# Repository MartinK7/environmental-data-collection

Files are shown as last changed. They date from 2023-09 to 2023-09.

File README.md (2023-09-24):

# Environmental-data-collection

##  TASK
Cílem projektu je sestavit systém, který bude schopen monitorovat vybrané meteorologická, případně hydropedologická data a odesílat je na servery pro IoT jako např. Thing Network, ThingSpeak, ubidots, aj. Snahou bude získaná data nejen archivovat, ale poskytnout je některé z předpovědních sítí jako OpenWeather, Weather Underground apod. MP(K)C-M2E: Prostudujte dostupné koncepce pro měření vybraných meteorologických veličin. Prostudujte možnosti řídícího prvku měřícího systému např. AVR, Raspberry Pi, STM32, ESP, aj. a zvolte ideální variantu. Prostudujte vhodné komunikační rozhraní pro přenos dat. Vyberte veškeré komponenty, navrhněte blokové schéma zařízení, sestavte obvodové zapojení, DPS a realizujte je. Při návrhu dbejte na nízkou spotřebu finálního zařízení a odolnost ve venkovním prostředí. MP(K)C-MSE: Zařízení zkompletujte, oživte, naprogramujte obslužné firmwary a zprovozněte sběr dat. Proveďte detailní testování celého systému a porovnejte jej s jinými řešeními. Měřená data poskytněte některé ze sítě pro sběr a předpověď počasí. Pozn.: Systém bude v budoucnu nasazen pro měřící stanici na střeše URELu. Výhodou je zkušenost s vývojem elektroniky a s programováním v jazyce C/C++ nebo Python.

## Basic literary sources
[1] KOUSAL, Martin. IoT monitoring ovzduší. Brno: Vysoké učení technické v Brně, Fakulta elektrotechniky a komunikačních technologií, Ústav radioelektroniky, 2022, 68 s. Bakalářská práce. Vedoucí práce: doc. Ing. Tomáš Frýza, Ph.D.

[2] Weather stations. OpenWeather [online]. 2022 [cit. 2022-05-24]. Dostupné z: https://openweathermap.org/stations

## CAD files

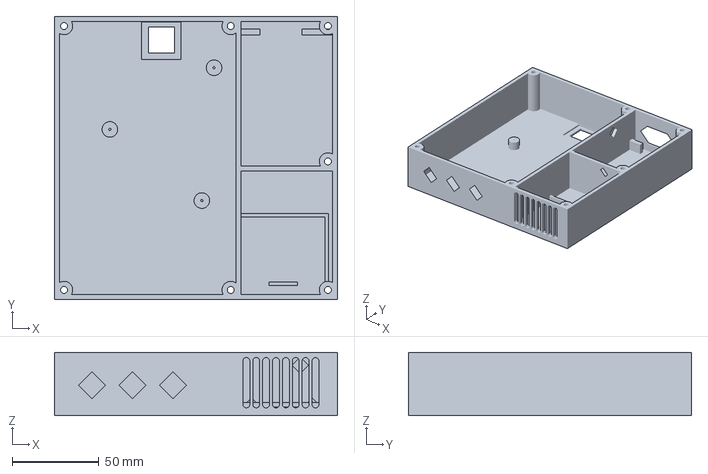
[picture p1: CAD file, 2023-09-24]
models/box4.3mf
163.0 x 163.0 x 36.5 mm

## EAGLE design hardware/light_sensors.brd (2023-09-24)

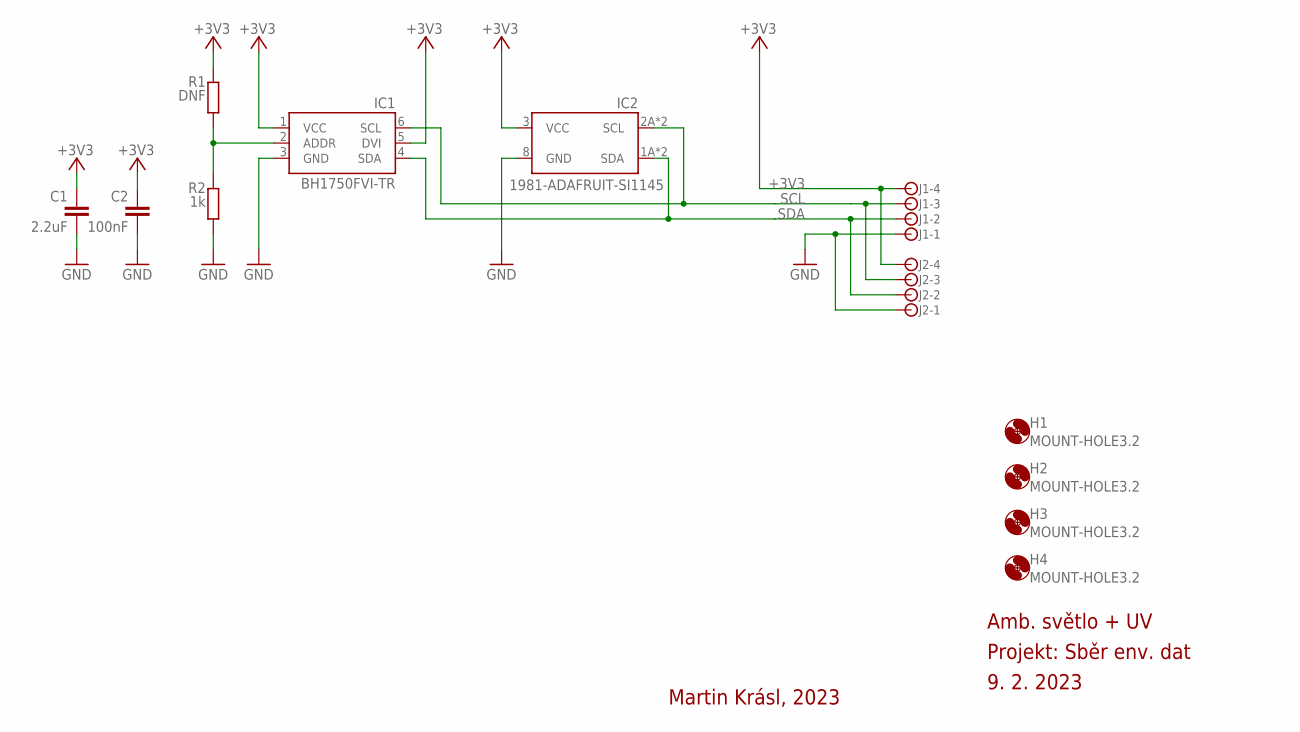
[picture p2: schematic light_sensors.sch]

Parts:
C1: 2.2uF; C0805
C2: 100nF; C0402
H1, H2, H3, H4: MOUNT-HOLE3.2; 3,2
IC1: BH1750FVI-TR; WSOF6
IC2: 1981-ADAFRUIT-SI1145
J1, J2: JST-XH-4; B4B-XH-A
R1: DNF; R0402
R2: 1k; R0402

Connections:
+3V3: C1.1, C2.1, IC1.1 (VCC), IC1.5 (DVI), IC2.3 (VCC), J1.4, J2.4, R1.2
GND: C1.2, C2.2, IC1.3 (GND), IC2.8 (GND), J1.1, J2.1, R2.1
unnamed: IC1.2 (ADDR), R1.1, R2.2
SCL: IC1.6 (SCL), IC2.2A (SCL), IC2.2B (SCL), J1.3, J2.3
SDA: IC1.4 (SDA), IC2.1A (SDA), IC2.1B (SDA), J1.2, J2.2

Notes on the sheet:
Amb. světlo + UV
Projekt: Sběr env. dat
9. 2. 2023
Martin Krásl, 2023

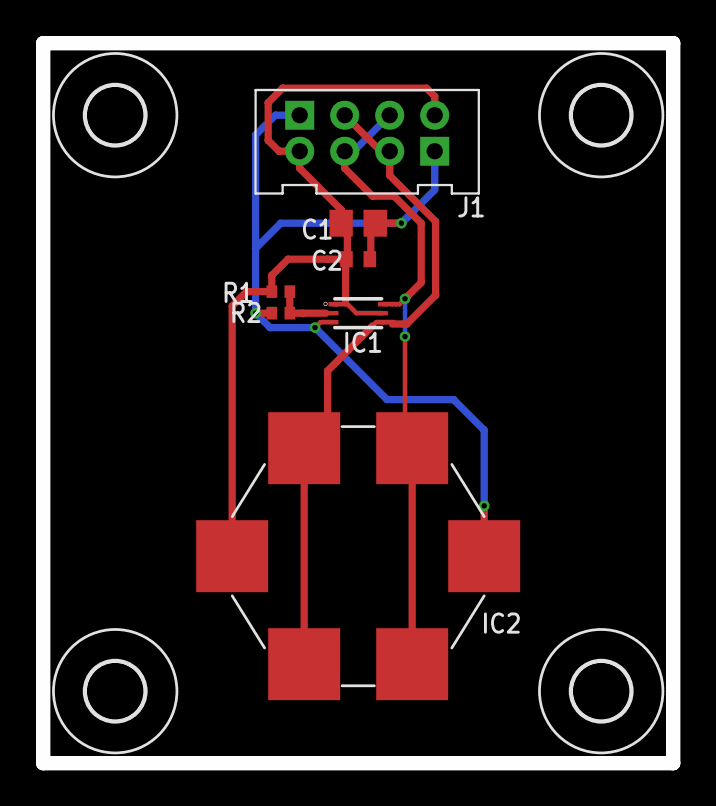
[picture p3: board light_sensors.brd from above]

Board: 2 copper layers, 35.0 x 40.0 mm, 12 parts (1 on the bottom side), 5 nets.

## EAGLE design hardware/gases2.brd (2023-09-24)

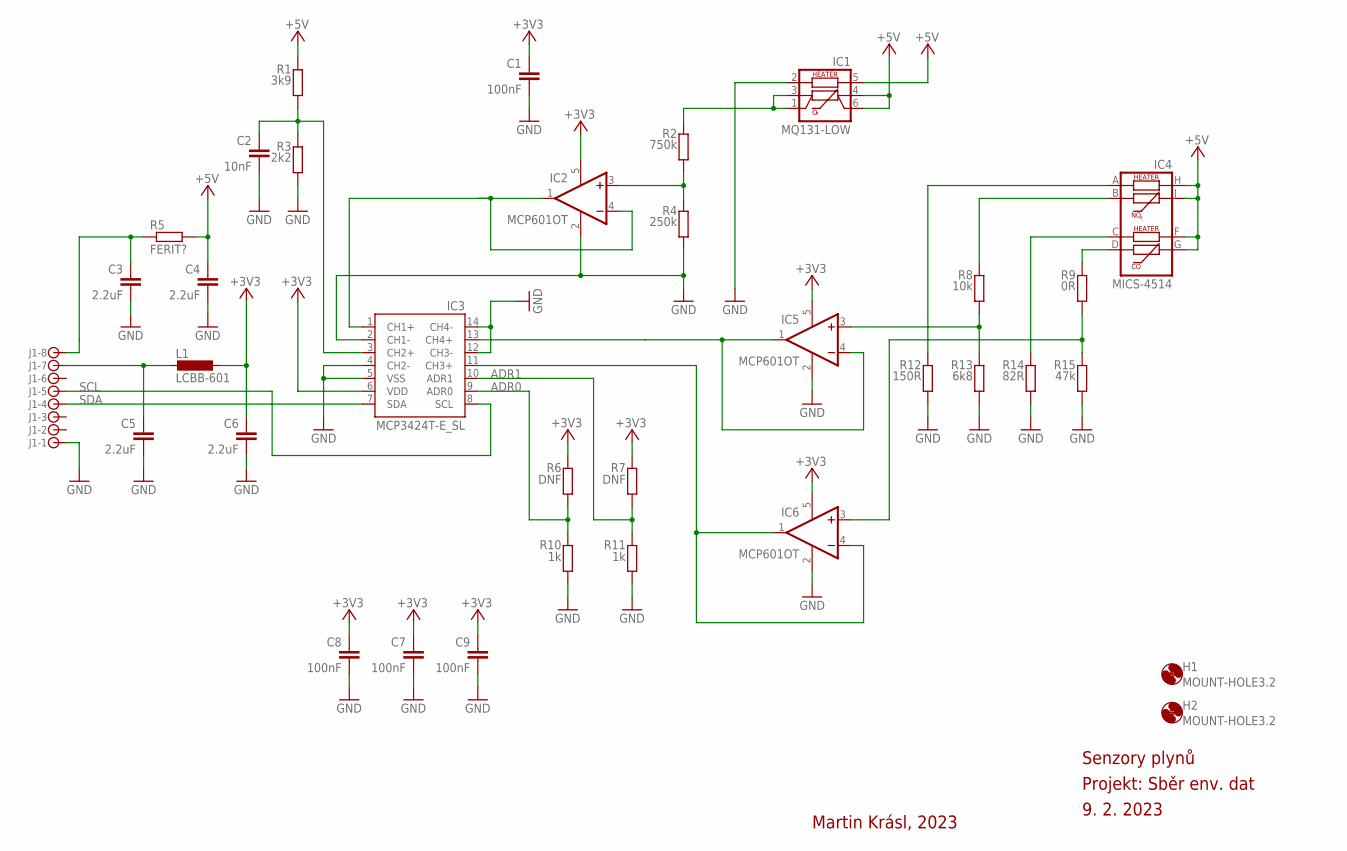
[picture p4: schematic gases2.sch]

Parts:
C1, C7, C8, C9: 100nF; C0402
C2: 10nF; C0402
C3, C4, C5, C6: 2.2uF; C0402
H1, H2: MOUNT-HOLE3.2; 3,2
IC1: MQ131-LOW
IC2, IC5, IC6: MCP601OT; SOT23-5
IC3: MCP3424T-E_SL; SOIC127P600X175-14N
IC4: MICS-4514
J1: JST-XH-8; B8B-XH-A
L1: LCBB-601; L2012C
R1: 3k9; R0402
R2: 750k; R0402
R3: 2k2; R0402
R4: 250k; R0402
R5: FERIT?; R0805
R6, R7: DNF; R0402
R8: 10k; R0402
R9: 0R; R0402
R10, R11: 1k; R0402
R12: 150R; R1206
R13: 6k8; R0402
R14: 82R; R1206
R15: 47k; R0402

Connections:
+3V3: C1.1, C6.1, C7.1, C8.1, C9.1, IC2.5 (V+), IC3.6 (VDD), IC5.5 (V+), IC6.5 (V+), L1.1, R6.2, R7.2
+5V: C4.1, IC1.4, IC1.5, IC1.6, IC4.F, IC4.G, IC4.H, IC4.J, R1.2, R5.2
ADR0: IC3.9 (ADR0), R6.1, R10.2
ADR1: IC3.10 (ADR1), R7.1, R11.2
GND: C1.2, C2.2, C3.2, C4.2, C5.2, C6.2, C7.2, C8.2, C9.2, IC1.2, IC2.2 (V-), IC3.2 (CH1-), IC3.4 (CH2-), IC3.5 (VSS), IC3.12 (CH3-), IC3.14 (CH4-), IC5.2 (V-), IC6.2 (V-), J1.1, R3.1, R4.1, R10.1, R11.1, R12.1, R13.1, R14.1, R15.1
unnamed: IC2.1 (OUT), IC2.4 (-IN), IC3.1 (CH1+)
unnamed: C2.1, IC3.3 (CH2+), R1.1, R3.2
unnamed: C3.1, J1.8, R5.1
unnamed: IC2.3 (+IN), R2.1, R4.2
unnamed: IC1.1, IC1.3, R2.2
unnamed: IC4.B, R8.2
unnamed: IC4.D, R9.2
unnamed: IC5.3 (+IN), R8.1, R13.2
unnamed: IC4.A, R12.2
unnamed: IC4.C, R14.2
unnamed: C5.1, J1.7, L1.2
unnamed: IC6.3 (+IN), R9.1, R15.2
unnamed: IC3.13 (CH4+), IC5.1 (OUT), IC5.4 (-IN)
unnamed: IC3.11 (CH3+), IC6.1 (OUT), IC6.4 (-IN)
SCL: IC3.8 (SCL), J1.5
SDA: IC3.7 (SDA), J1.4

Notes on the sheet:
Senzory plynů
Projekt: Sběr env. dat
9. 2. 2023
Martin Krásl, 2023

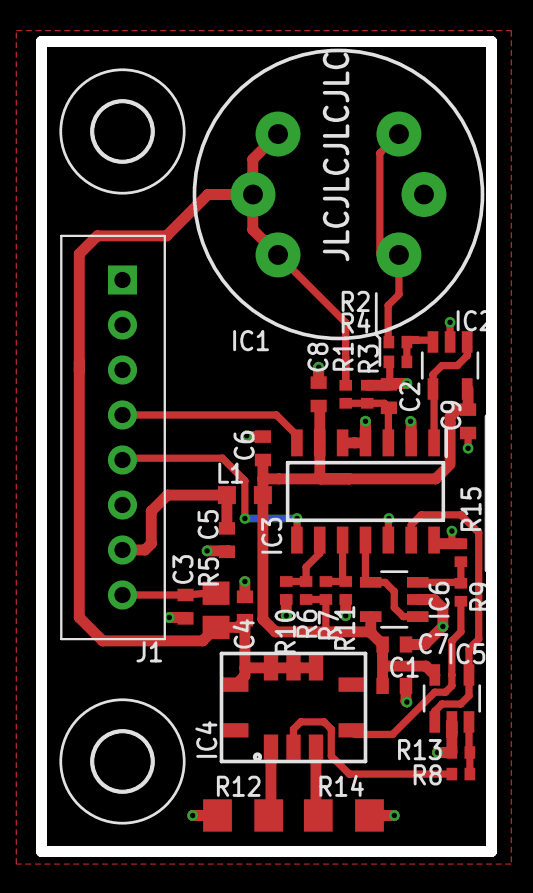
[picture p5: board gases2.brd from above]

Board: 2 copper layers, 25.0 x 45.0 mm, 34 parts (0 on the bottom side), 21 nets.

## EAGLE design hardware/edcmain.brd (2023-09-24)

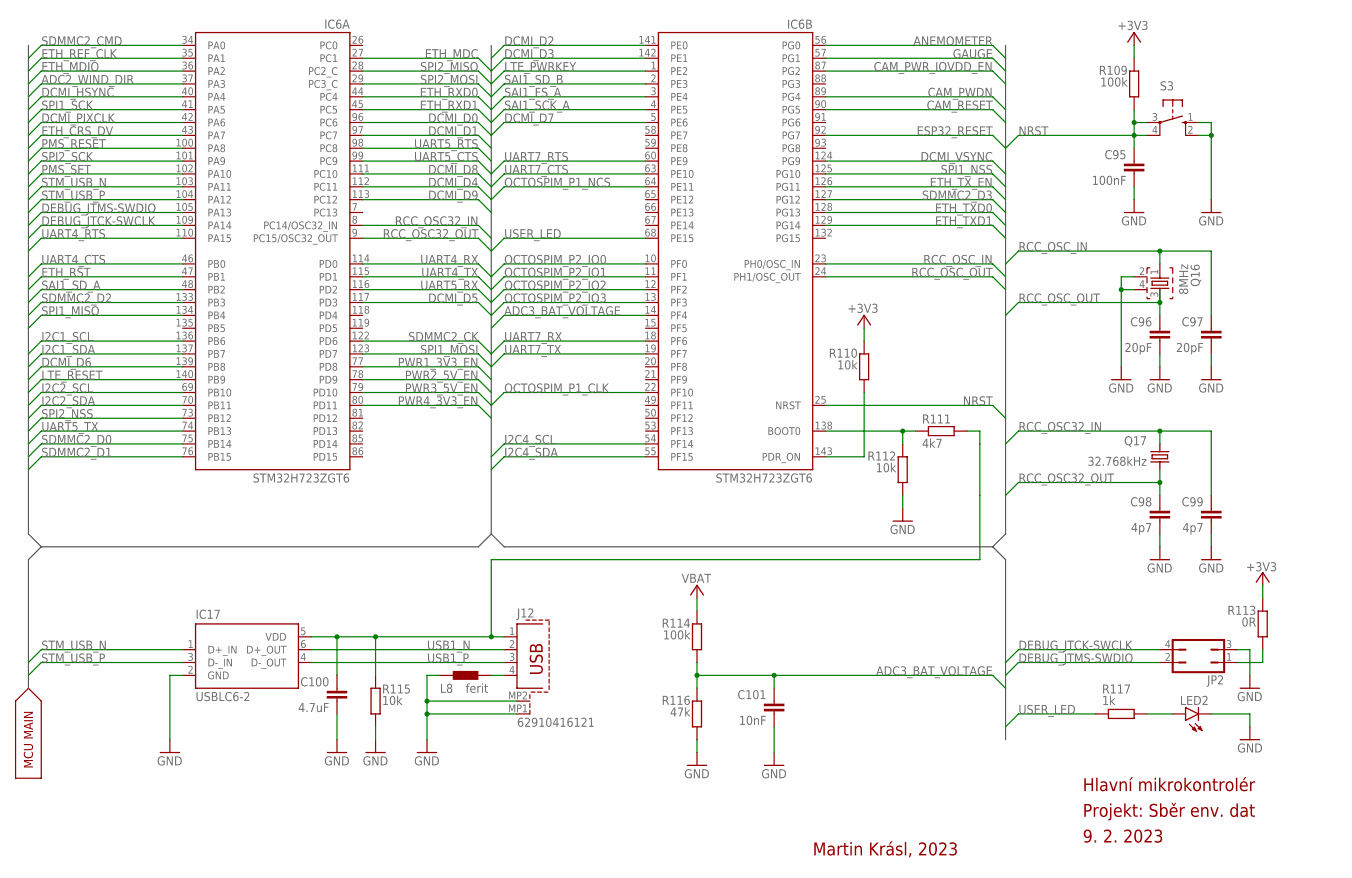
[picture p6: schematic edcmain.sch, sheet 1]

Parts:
C95: 100nF; C0402
C96, C97: 20pF; C0402
C98, C99: 4p7; C0402
C100: 4.7uF; C0402
C101: 10nF; C0402
IC6: STM32H723ZGT6; QFP50P2200X2200X160-144N
IC17: USBLC6-2; SOT23-6
J12: 62910416121
JP2: JP2Q
L8: ferit; 0402
LED2: LEDCHIP-LED0805; CHIP-LED0805
Q16: 8MHz; CRYSTAL3.2X2.5
Q17: 32.768kHz; NX3215SA32768KEXS00AMU00003
R109, R114: 100k; R0402
R110, R112, R115: 10k; R0402
R111: 4k7; R0402
R113: 0R; R0402
R116: 47k; R0402
R117: 1k; R0402
S3: 10-XX; B3F-10XX

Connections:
+3V3: R109.2, R110.2, R113.2; also elsewhere on the board
ADC2_WIND_DIR: IC6.37 (PA3); also elsewhere on the board
ADC3_BAT_VOLTAGE: C101.1, IC6.14 (PF4), R114.1, R116.2
ANEMOMETER: IC6.56 (PG0); also elsewhere on the board
CAM_PWDN: IC6.89 (PG4); also elsewhere on the board
CAM_PWR_IOVDD_EN: IC6.87 (PG2); also elsewhere on the board
CAM_RESET: IC6.90 (PG5); also elsewhere on the board
DCMI_D0: IC6.96 (PC6); also elsewhere on the board
DCMI_D1: IC6.97 (PC7); also elsewhere on the board
DCMI_D2: IC6.141 (PE0); also elsewhere on the board
DCMI_D3: IC6.142 (PE1); also elsewhere on the board
DCMI_D4: IC6.112 (PC11); also elsewhere on the board
DCMI_D5: IC6.117 (PD3); also elsewhere on the board
DCMI_D6: IC6.139 (PB8); also elsewhere on the board
DCMI_D7: IC6.5 (PE6); also elsewhere on the board
DCMI_D8: IC6.111 (PC10); also elsewhere on the board
DCMI_D9: IC6.113 (PC12); also elsewhere on the board
DCMI_HSYNC: IC6.40 (PA4); also elsewhere on the board
DCMI_PIXCLK: IC6.42 (PA6); also elsewhere on the board
DCMI_VSYNC: IC6.124 (PG9); also elsewhere on the board
DEBUG_JTCK-SWCLK: IC6.109 (PA14), JP2.4
DEBUG_JTMS-SWDIO: IC6.105 (PA13), JP2.2
ESP32_RESET: IC6.92 (PG7); also elsewhere on the board
ETH_CRS_DV: IC6.43 (PA7); also elsewhere on the board
ETH_MDC: IC6.27 (PC1); also elsewhere on the board
ETH_MDIO: IC6.36 (PA2); also elsewhere on the board
ETH_REF_CLK: IC6.35 (PA1); also elsewhere on the board
ETH_RST: IC6.47 (PB1); also elsewhere on the board
ETH_RXD0: IC6.44 (PC4); also elsewhere on the board
ETH_RXD1: IC6.45 (PC5); also elsewhere on the board
ETH_TXD0: IC6.128 (PG13); also elsewhere on the board
ETH_TXD1: IC6.129 (PG14); also elsewhere on the board
ETH_TX_EN: IC6.126 (PG11); also elsewhere on the board
GAUGE: IC6.57 (PG1); also elsewhere on the board
GND: C95.2, C96.2, C97.2, C98.2, C99.2, C100.2, C101.2, IC17.2 (GND), J12.MP1, J12.MP2, JP2.3, L8.1, LED2.C, Q16.2, Q16.4, R112.1, R115.1, R116.1, S3.1 (S), S3.2 (S1); also elsewhere on the board
I2C1_SCL: IC6.136 (PB6); also elsewhere on the board
I2C1_SDA: IC6.137 (PB7); also elsewhere on the board
I2C2_SCL: IC6.69 (PB10); also elsewhere on the board
I2C2_SDA: IC6.70 (PB11); also elsewhere on the board
I2C4_SCL: IC6.54 (PF14); also elsewhere on the board
I2C4_SDA: IC6.55 (PF15); also elsewhere on the board
LTE_PWRKEY: IC6.1 (PE2); also elsewhere on the board
LTE_RESET: IC6.140 (PB9); also elsewhere on the board
unnamed: C100.1, IC17.5 (VDD), J12.1, R111.2, R115.2
unnamed: LED2.A, R117.2
unnamed: IC6.143 (PDR_ON), R110.1
unnamed: IC6.138 (BOOT0), R111.1, R112.2
unnamed: J12.4, L8.2
unnamed: JP2.1, R113.1
NRST: C95.1, IC6.25 (NRST), R109.1, S3.3, S3.4 (P1)
OCTOSPIM_P1_CLK: IC6.22 (PF10); also elsewhere on the board
OCTOSPIM_P1_NCS: IC6.64 (PE11); also elsewhere on the board
OCTOSPIM_P2_IO0: IC6.10 (PF0); also elsewhere on the board
OCTOSPIM_P2_IO1: IC6.11 (PF1); also elsewhere on the board
OCTOSPIM_P2_IO2: IC6.12 (PF2); also elsewhere on the board
OCTOSPIM_P2_IO3: IC6.13 (PF3); also elsewhere on the board
PMS_RESET: IC6.100 (PA8); also elsewhere on the board
PMS_SET: IC6.102 (PA10); also elsewhere on the board
PWR1_3V3_EN: IC6.77 (PD8); also elsewhere on the board
PWR2_5V_EN: IC6.78 (PD9); also elsewhere on the board
PWR3_5V_EN: IC6.79 (PD10); also elsewhere on the board
PWR4_3V3_EN: IC6.80 (PD11); also elsewhere on the board
RCC_OSC32_IN: C99.1, IC6.8 (PC14/OSC32_IN), Q17.2
RCC_OSC32_OUT: C98.1, IC6.9 (PC15/OSC32_OUT), Q17.1
RCC_OSC_IN: C97.1, IC6.23 (PH0/OSC_IN), Q16.1
RCC_OSC_OUT: C96.1, IC6.24 (PH1/OSC_OUT), Q16.3
SAI1_FS_A: IC6.3 (PE4); also elsewhere on the board
SAI1_SCK_A: IC6.4 (PE5); also elsewhere on the board
SAI1_SD_A: IC6.48 (PB2); also elsewhere on the board
SAI1_SD_B: IC6.2 (PE3); also elsewhere on the board
SDMMC2_CK: IC6.122 (PD6); also elsewhere on the board
SDMMC2_CMD: IC6.34 (PA0); also elsewhere on the board
SDMMC2_D0: IC6.75 (PB14); also elsewhere on the board
SDMMC2_D1: IC6.76 (PB15); also elsewhere on the board
SDMMC2_D2: IC6.133 (PB3); also elsewhere on the board
SDMMC2_D3: IC6.127 (PG12); also elsewhere on the board
SPI1_MISO: IC6.134 (PB4); also elsewhere on the board
SPI1_MOSI: IC6.123 (PD7); also elsewhere on the board
SPI1_NSS: IC6.125 (PG10); also elsewhere on the board
SPI1_SCK: IC6.41 (PA5); also elsewhere on the board
SPI2_MISO: IC6.28 (PC2_C); also elsewhere on the board
SPI2_MOSI: IC6.29 (PC3_C); also elsewhere on the board
SPI2_NSS: IC6.73 (PB12); also elsewhere on the board
SPI2_SCK: IC6.101 (PA9); also elsewhere on the board
STM_USB_N: IC6.103 (PA11), IC17.1 (D+_IN)
STM_USB_P: IC6.104 (PA12), IC17.3 (D-_IN)
UART4_CTS: IC6.46 (PB0); also elsewhere on the board
UART4_RTS: IC6.110 (PA15); also elsewhere on the board
UART4_RX: IC6.114 (PD0); also elsewhere on the board
UART4_TX: IC6.115 (PD1); also elsewhere on the board
UART5_CTS: IC6.99 (PC9); also elsewhere on the board
UART5_RTS: IC6.98 (PC8); also elsewhere on the board
UART5_RX: IC6.116 (PD2); also elsewhere on the board
UART5_TX: IC6.74 (PB13); also elsewhere on the board
UART7_CTS: IC6.63 (PE10); also elsewhere on the board
UART7_RTS: IC6.60 (PE9); also elsewhere on the board
UART7_RX: IC6.18 (PF6); also elsewhere on the board
UART7_TX: IC6.19 (PF7); also elsewhere on the board
USB1_N: IC17.6 (D+_OUT), J12.2
USB1_P: IC17.4 (D-_OUT), J12.3
USER_LED: IC6.68 (PE15), R117.1
VBAT: R114.2; also elsewhere on the board

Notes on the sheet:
MCU MAIN
Hlavní mikrokontrolér
Projekt: Sběr env. dat
9. 2. 2023
Martin Krásl, 2023

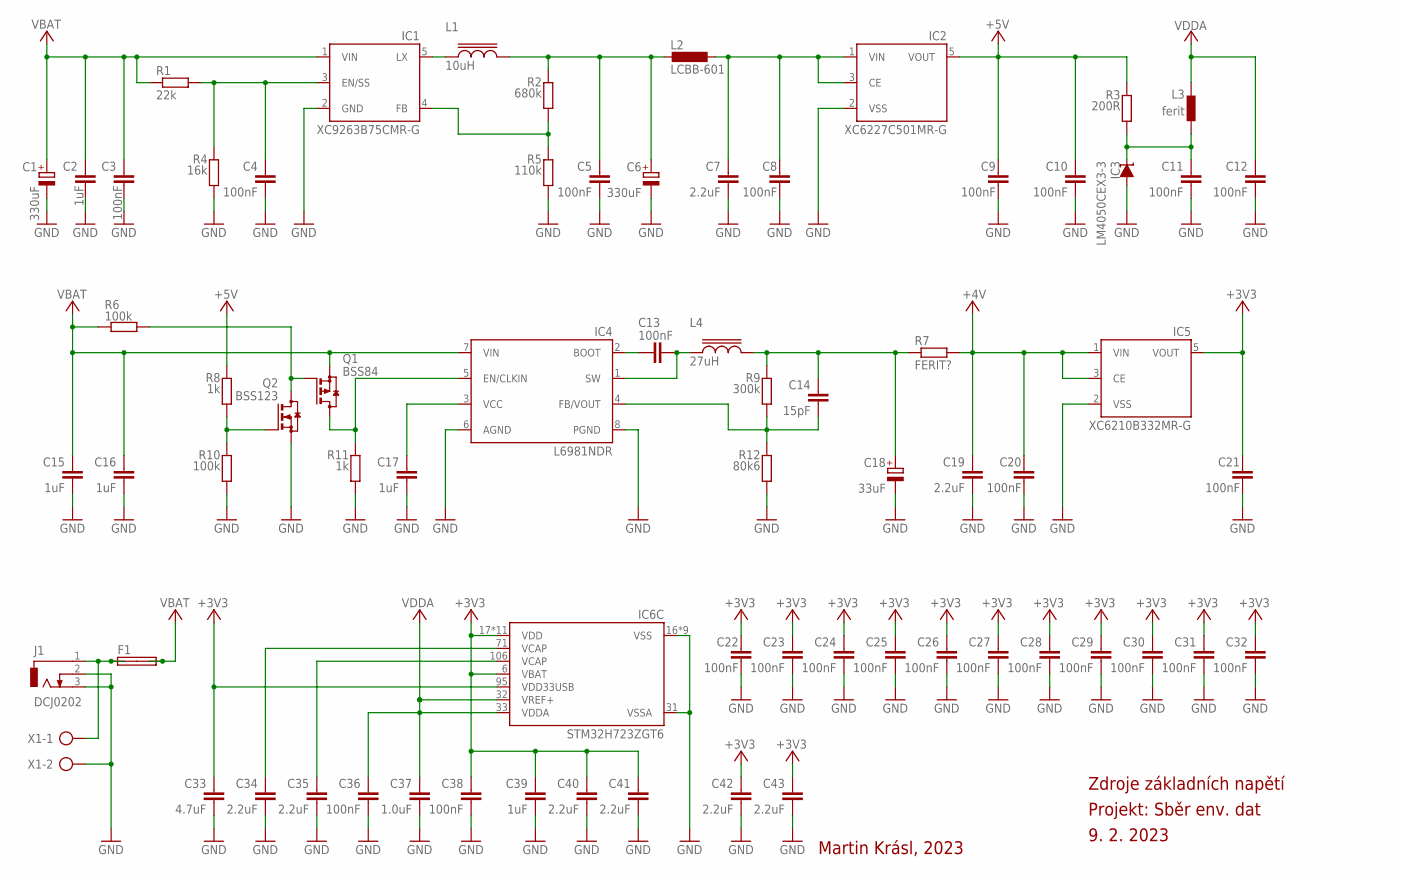
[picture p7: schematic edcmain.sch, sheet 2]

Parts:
C1, C6: 330uF; PANASONIC_G
C2, C15, C16: 1uF; C0805
C3, C4, C5, C8, C9, C10, C11, C12, C13, C20, C21, C22, C23, C24, C25, C26, C27, C28, C29, C30, C31, C32, C36, C38: 100nF; C0402
C7, C34, C35, C43: 2.2uF; C0805
C14: 15pF; C0402
C17, C39: 1uF; C0402
C18: 33uF; PANASONIC_G
C19, C40, C41, C42: 2.2uF; C0402
C33: 4.7uF; C0402
C37: 1.0uF; C0402
F1: SHK20L
IC1: XC9263B75CMR-G; SOT95P280X130-5N
IC2: XC6227C501MR-G; SOT95P280X130-5N
IC3: LM4050CEX3-3; SC70-3
IC4: L6981NDR; SOIC127P600X175-8N
IC5: XC6210B332MR-G; SOT95P280X130-5N
IC6: STM32H723ZGT6; QFP50P2200X2200X160-144N
IMG1: IMAGEPRINT; RD_14_24_PRINT
J1: DCJ0202
L1: 10uH; L6
L2: LCBB-601; L2012C
L3: ferit; 0402
L4: 27uH; L6
Q1: BSS84; SOT23
Q2: BSS123; SOT23
R1: 22k; R0402
R2: 680k; R0402
R3: 200R; R0402
R4: 16k; R0402
R5: 110k; R0402
R6, R10: 100k; R0402
R7: FERIT?; R2010
R8, R11: 1k; R0402
R9: 300k; R0402
R12: 80k6; R0402
X1: AK500/2

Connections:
+3V3: C21.1, C22.1, C23.1, C24.1, C25.1, C26.1, C27.1, C28.1, C29.1, C30.1, C31.1, C32.1, C33.1, C38.1, C39.1, C40.1, C41.1, C42.1, C43.1, IC5.5 (VOUT), IC6.6 (VBAT), IC6.17 (VDD), IC6.30 (VDD), IC6.39 (VDD), IC6.52 (VDD), IC6.62 (VDD), IC6.72 (VDD), IC6.84 (VDD), IC6.95 (VDD33USB), IC6.108 (VDD), IC6.121 (VDD), IC6.131 (VDD), IC6.144 (VDD); also elsewhere on the board
+4V: C19.1, C20.1, IC5.1 (VIN), IC5.3 (CE), R7.2; also elsewhere on the board
+5V: C9.1, C10.1, IC2.5 (VOUT), R3.2, R8.2; also elsewhere on the board
GND: C1.-, C2.2, C3.2, C4.2, C5.2, C6.-, C7.2, C8.2, C9.2, C10.2, C11.2, C12.2, C15.2, C16.2, C17.2, C18.-, C19.2, C20.2, C21.2, C22.2, C23.2, C24.2, C25.2, C26.2, C27.2, C28.2, C29.2, C30.2, C31.2, C32.2, C33.2, C34.2, C35.2, C36.2, C37.2, C38.2, C39.2, C40.2, C41.2, C42.2, C43.2, IC1.2 (GND), IC2.2 (VSS), IC3.1 (A), IC4.6 (AGND), IC4.8 (PGND), IC5.2 (VSS), IC6.16 (VSS), IC6.31 (VSSA), IC6.38 (VSS), IC6.51 (VSS), IC6.61 (VSS), IC6.83 (VSS), IC6.94 (VSS), IC6.107 (VSS), IC6.120 (VSS), IC6.130 (VSS), J1.2, J1.3, Q2.2 (S), R4.1, R5.1, R10.1, R11.1, R12.1, X1.2; also elsewhere on the board
unnamed: F1.1A, F1.1B, J1.1, X1.1
unnamed: C34.1, IC6.71 (VCAP)
unnamed: C35.1, IC6.106 (VCAP)
unnamed: C11.1, IC3.2 (C), L3.1, R3.1
unnamed: C17.1, IC4.3 (VCC)
unnamed: C7.1, C8.1, IC2.1 (VIN), IC2.3 (CE), L2.1
unnamed: C5.1, C6.+, L1.P$2, L2.2, R2.2
unnamed: IC1.5 (LX), L1.P$1
unnamed: IC1.4 (FB), R2.1, R5.2
unnamed: C4.1, IC1.3 (EN/SS), R1.2, R4.2
unnamed: C14.2, IC4.4 (FB/VOUT), R9.1, R12.2
unnamed: C13.1, IC4.2 (BOOT)
unnamed: C13.2, IC4.1 (SW), L4.P$1
unnamed: C14.1, C18.+, L4.P$2, R7.1, R9.2
unnamed: Q1.1 (G), Q2.3 (D), R6.2
unnamed: IC4.5 (EN/CLKIN), Q1.3 (D), R11.2
unnamed: Q2.1 (G), R8.1, R10.2
VBAT: C1.+, C2.1, C3.1, C15.1, C16.1, F1.2A, F1.2B, IC1.1 (VIN), IC4.7 (VIN), Q1.2 (S), R1.1, R6.1; also elsewhere on the board
VDDA: C12.1, C36.1, C37.1, IC6.32 (VREF+), IC6.33 (VDDA), L3.2

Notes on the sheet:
Zdroje základních napětí
Projekt: Sběr env. dat
9. 2. 2023
Martin Krásl, 2023

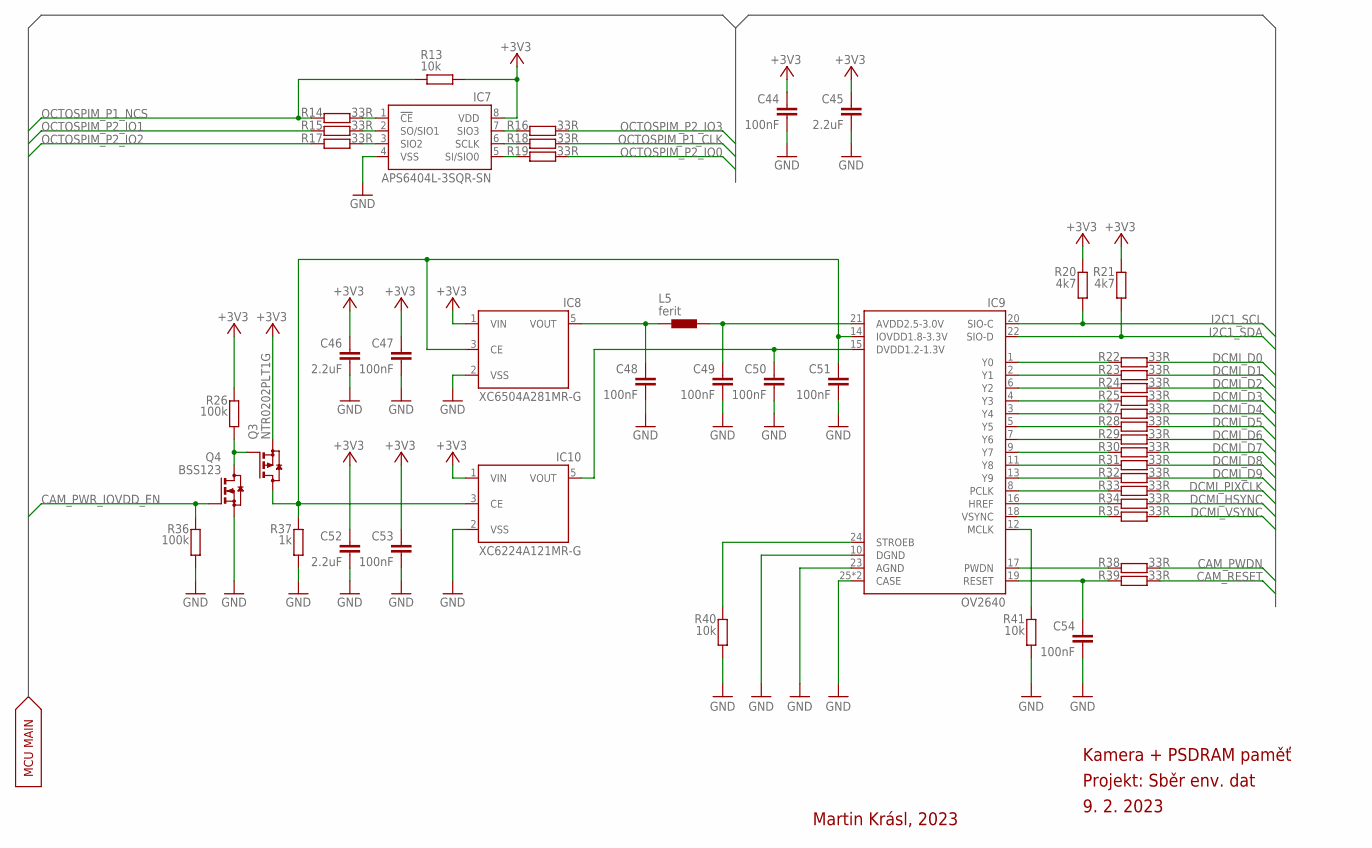
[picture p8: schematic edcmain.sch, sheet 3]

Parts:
C44, C47, C48, C49, C50, C51, C53, C54: 100nF; C0402
C45, C46: 2.2uF; C0402
C52: 2.2uF; C0805
IC7: APS6404L-3SQR-SN; SOP08
IC8: XC6504A281MR-G; SOT95P280X130-5N
IC9: OV2640; XF2M-2415-1A-SWAP
IC10: XC6224A121MR-G; SOT95P280X130-5N
L5: ferit; 0402
Q3: NTR0202PLT1G; SOT23
Q4: BSS123; SOT23
R13, R40, R41: 10k; R0402
R14, R15, R16, R17, R18, R19, R22, R23, R24, R25, R27, R28, R29, R30, R31, R32, R33, R34, R35, R38, R39: 33R; R0402
R20, R21: 4k7; R0402
R26, R36: 100k; R0402
R37: 1k; R0402

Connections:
+3V3: C44.1, C45.1, C46.1, C47.1, C52.1, C53.1, IC7.8 (VDD), IC8.1 (VIN), IC10.1 (VIN), Q3.2 (S), R13.2, R20.2, R21.2, R26.2; also elsewhere on the board
CAM_PWDN: R38.2; also elsewhere on the board
CAM_PWR_IOVDD_EN: Q4.1 (G), R36.2; also elsewhere on the board
CAM_RESET: R39.2; also elsewhere on the board
DCMI_D0: R22.2; also elsewhere on the board
DCMI_D1: R23.2; also elsewhere on the board
DCMI_D2: R24.2; also elsewhere on the board
DCMI_D3: R25.2; also elsewhere on the board
DCMI_D4: R27.2; also elsewhere on the board
DCMI_D5: R28.2; also elsewhere on the board
DCMI_D6: R29.2; also elsewhere on the board
DCMI_D7: R30.2; also elsewhere on the board
DCMI_D8: R31.2; also elsewhere on the board
DCMI_D9: R32.2; also elsewhere on the board
DCMI_HSYNC: R34.2; also elsewhere on the board
DCMI_PIXCLK: R33.2; also elsewhere on the board
DCMI_VSYNC: R35.2; also elsewhere on the board
GND: C44.2, C45.2, C46.2, C47.2, C48.2, C49.2, C50.2, C51.2, C52.2, C53.2, C54.2, IC7.4 (VSS), IC8.2 (VSS), IC9.10 (DGND), IC9.23 (AGND), IC9.25 (CASE), IC9.26 (CASE), IC10.2 (VSS), Q4.2 (S), R36.1, R37.1, R40.1, R41.1; also elsewhere on the board
I2C1_SCL: IC9.20 (SIO-C), R20.1; also elsewhere on the board
I2C1_SDA: IC9.22 (SIO-D), R21.1; also elsewhere on the board
unnamed: IC9.1 (Y0), R22.1
unnamed: IC9.2 (Y1), R23.1
unnamed: IC9.6 (Y2), R24.1
unnamed: IC9.4 (Y3), R25.1
unnamed: IC9.3 (Y4), R27.1
unnamed: IC9.5 (Y5), R28.1
unnamed: IC9.7 (Y6), R29.1
unnamed: IC9.9 (Y7), R30.1
unnamed: IC9.11 (Y8), R31.1
unnamed: IC9.13 (Y9), R32.1
unnamed: IC7.1 (!CE!), R14.2
unnamed: IC7.2 (SO/SIO1), R15.2
unnamed: IC7.3 (SIO2), R17.2
unnamed: IC7.7 (SIO3), R16.1
unnamed: IC7.6 (SCLK), R18.1
unnamed: IC7.5 (SI/SIO0), R19.1
unnamed: IC9.18 (VSYNC), R35.1
unnamed: IC9.16 (HREF), R34.1
unnamed: IC9.8 (PCLK), R33.1
unnamed: C48.1, IC8.5 (VOUT), L5.1
unnamed: C49.1, IC9.21 (AVDD2.5-3.0V), L5.2
unnamed: C50.1, IC9.15 (DVDD1.2-1.3V), IC10.5 (VOUT)
unnamed: IC9.24 (STROEB), R40.2
unnamed: IC9.17 (PWDN), R38.1
unnamed: IC9.12 (MCLK), R41.2
unnamed: C54.1, IC9.19 (RESET), R39.1
unnamed: Q3.1 (G), Q4.3 (D), R26.1
unnamed: C51.1, IC8.3 (CE), IC9.14 (IOVDD1.8-3.3V), IC10.3 (CE), Q3.3 (D), R37.2
OCTOSPIM_P1_CLK: R18.2; also elsewhere on the board
OCTOSPIM_P1_NCS: R13.1, R14.1; also elsewhere on the board
OCTOSPIM_P2_IO0: R19.2; also elsewhere on the board
OCTOSPIM_P2_IO1: R15.1; also elsewhere on the board
OCTOSPIM_P2_IO2: R17.1; also elsewhere on the board
OCTOSPIM_P2_IO3: R16.2; also elsewhere on the board

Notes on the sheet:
MCU MAIN
Kamera + PSDRAM paměť
Projekt: Sběr env. dat
9. 2. 2023
Martin Krásl, 2023

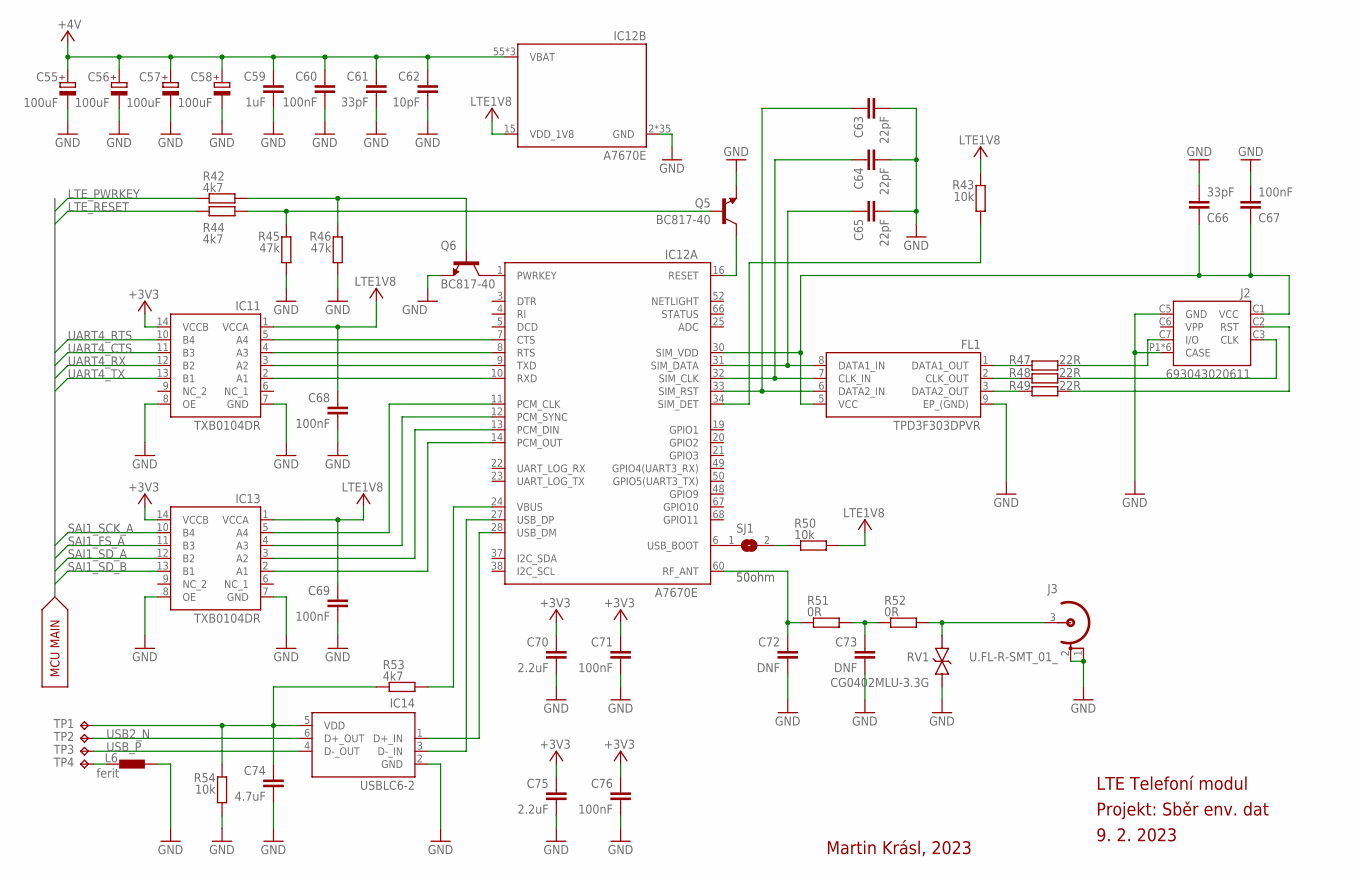
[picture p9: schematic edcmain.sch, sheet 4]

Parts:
C55, C56, C57, C58: 100uF; B/3528-21R
C59: 1uF; C0805
C60, C67, C68, C69, C71, C76: 100nF; C0402
C61, C66: 33pF; C0402
C62: 10pF; C0402
C63, C64, C65: 22pF; C0402
C70, C75: 2.2uF; C0402
C72, C73: DNF; C0402
C74: 4.7uF; C0402
FL1: TPD3F303DPVR; SON50P160X210X65-9N
IC11, IC13: TXB0104DR; SOIC127P600X175-14N
IC12: A7670E; A7670CLNSC
IC14: USBLC6-2; SOT23-6
J2: 693043020611
J3: U.FL-R-SMT_01_; UFLRSMT01
L6: ferit; 0402
Q5, Q6: BC817-40; SOT23-BEC
R42, R44, R53: 4k7; R0402
R43, R50, R54: 10k; R0402
R45, R46: 47k; R0402
R47, R48, R49: 22R; R0402
R51, R52: 0R; R0402
RV1: CG0402MLU-3.3G; VARC1005X41N
SJ1: SJ
TP1, TP2, TP3, TP4: TPB1,27; B1,27

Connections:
50OHM_1: C72.1, IC12.60 (RF_ANT), R51.1
50OHM_2: C73.1, R51.2, R52.1
50OHM_3: J3.3 (SIG), R52.2, RV1.1
+3V3: C70.1, C71.1, C75.1, C76.1, IC11.14 (VCCB), IC13.14 (VCCB); also elsewhere on the board
+4V: C55.+, C56.+, C57.+, C58.+, C59.1, C60.1, C61.1, C62.1, IC12.55 (VBAT), IC12.56 (VBAT), IC12.57 (VBAT); also elsewhere on the board
GND: C55.-, C56.-, C57.-, C58.-, C59.2, C60.2, C61.2, C62.2, C63.2, C64.2, C65.2, C66.2, C67.2, C68.2, C69.2, C70.2, C71.2, C72.2, C73.2, C74.2, C75.2, C76.2, FL1.9 (EP_(GND)), IC11.7 (GND), IC11.8 (OE), IC12.2 (GND), IC12.17 (GND), IC12.18 (GND), IC12.29 (GND), IC12.39 (GND), IC12.45 (GND), IC12.46 (GND), IC12.54 (GND), IC12.58 (GND), IC12.59 (GND), IC12.61 (GND), IC12.62 (GND), IC12.63 (GND), IC12.64 (GND), IC12.65 (GND), IC12.69 (GND), IC12.70 (GND), IC12.71 (GND), IC12.72 (GND), IC12.73 (GND), IC12.74 (GND), IC12.75 (GND), IC12.76 (GND), IC12.77 (GND), IC12.78 (GND), IC12.79 (GND), IC12.80 (GND), IC12.81 (GND), IC12.82 (GND), IC12.83 (GND), IC12.84 (GND), IC12.85 (GND), IC12.86 (GND), IC12.87 (GND), IC12.88 (GND), IC13.7 (GND), IC13.8 (OE), IC14.2 (GND), J2.C5 (GND), J2.P1 (CASE), J2.P2 (CASE), J2.P3 (CASE), J2.P4 (CASE), J2.P5 (CASE), J2.P6 (CASE), J3.1 (GND), J3.2 (GND), L6.1, Q5.E, Q6.E, R45.1, R46.1, R54.1, RV1.2; also elsewhere on the board
LTE1V8: C68.1, C69.1, IC11.1 (VCCA), IC12.15 (VDD_1V8), IC13.1 (VCCA), R43.2, R50.2
LTE_PWRKEY: R42.1; also elsewhere on the board
LTE_RESET: R44.1; also elsewhere on the board
unnamed: IC11.5 (A4), IC12.7 (CTS)
unnamed: IC11.4 (A3), IC12.8 (RTS)
unnamed: IC11.3 (A2), IC12.9 (TXD)
unnamed: IC11.2 (A1), IC12.10 (RXD)
unnamed: IC12.11 (PCM_CLK), IC13.5 (A4)
unnamed: IC12.12 (PCM_SYNC), IC13.4 (A3)
unnamed: IC12.13 (PCM_DIN), IC13.3 (A2)
unnamed: IC12.14 (PCM_OUT), IC13.2 (A1)
unnamed: C66.1, C67.1, FL1.5 (VCC), IC12.30 (SIM_VDD), J2.C1 (VCC)
unnamed: J2.C2 (RST), R49.2
unnamed: J2.C3 (CLK), R48.2
unnamed: J2.C7 (I/O), R47.2
unnamed: C63.1, FL1.6 (DATA2_IN), IC12.33 (SIM_RST)
unnamed: C64.1, FL1.7 (CLK_IN), IC12.32 (SIM_CLK)
unnamed: C65.1, FL1.8 (DATA1_IN), IC12.31 (SIM_DATA)
unnamed: IC12.34 (SIM_DET), R43.1
unnamed: C74.1, IC14.5 (VDD), R53.1, R54.2, TP1.TP
unnamed: L6.2, TP4.TP
unnamed: IC12.27 (USB_DP), IC14.3 (D-_IN)
unnamed: IC12.28 (USB_DM), IC14.1 (D+_IN)
unnamed: IC12.24 (VBUS), R53.2
unnamed: IC12.1 (PWRKEY), Q6.C
unnamed: IC12.6 (USB_BOOT), SJ1.1
unnamed: Q6.B, R42.2, R46.2
unnamed: IC12.16 (RESET), Q5.C
unnamed: R50.1, SJ1.2
unnamed: Q5.B, R44.2, R45.2
unnamed: FL1.3 (DATA2_OUT), R49.1
unnamed: FL1.2 (CLK_OUT), R48.1
unnamed: FL1.1 (DATA1_OUT), R47.1
SAI1_FS_A: IC13.11 (B3); also elsewhere on the board
SAI1_SCK_A: IC13.10 (B4); also elsewhere on the board
SAI1_SD_A: IC13.12 (B2); also elsewhere on the board
SAI1_SD_B: IC13.13 (B1); also elsewhere on the board
UART4_CTS: IC11.11 (B3); also elsewhere on the board
UART4_RTS: IC11.10 (B4); also elsewhere on the board
UART4_RX: IC11.12 (B2); also elsewhere on the board
UART4_TX: IC11.13 (B1); also elsewhere on the board
USB2_N: IC14.6 (D+_OUT), TP2.TP
USB_P: IC14.4 (D-_OUT), TP3.TP

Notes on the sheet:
MCU MAIN
50ohm
LTE Telefoní modul
Projekt: Sběr env. dat
9. 2. 2023
Martin Krásl, 2023

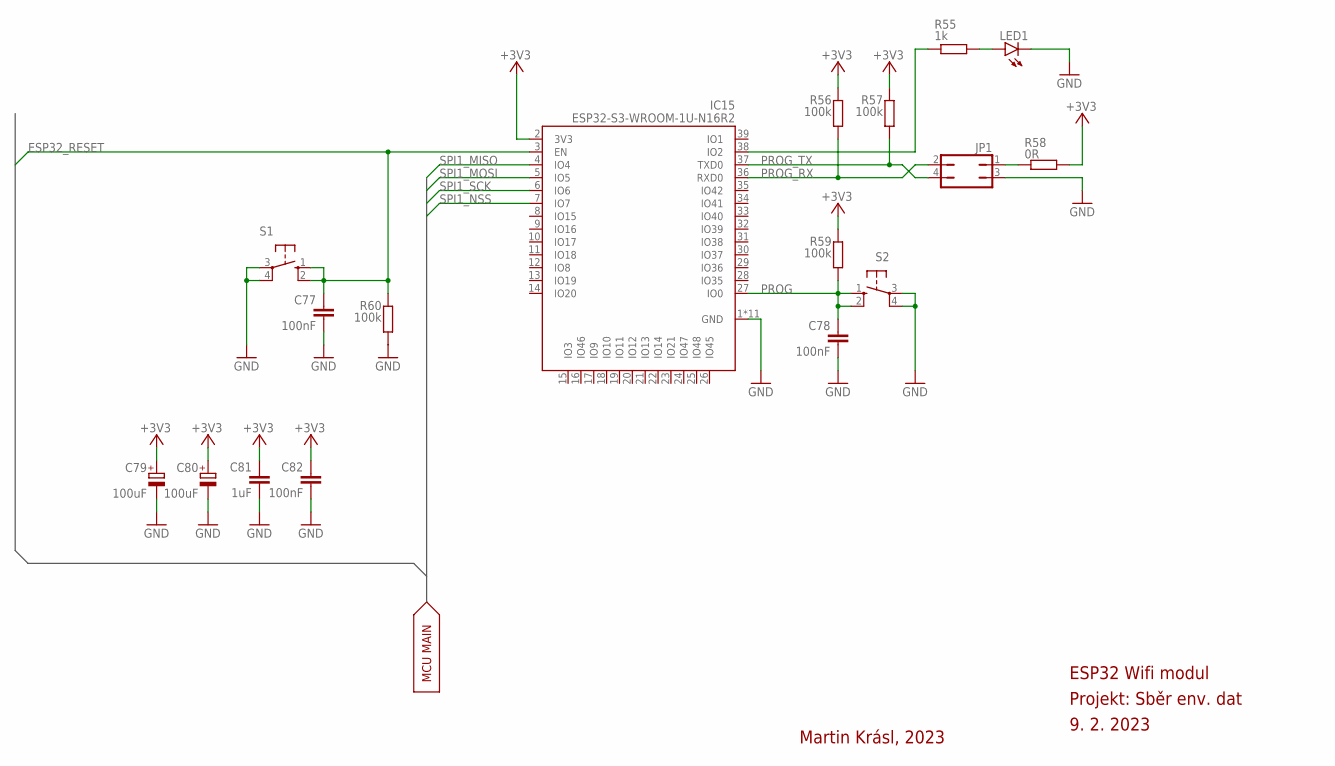
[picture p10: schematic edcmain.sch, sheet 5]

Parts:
C77, C78, C82: 100nF; C0402
C79, C80: 100uF; B/3528-21R
C81: 1uF; C0805
IC15: ESP32-S3-WROOM-1U-N16R2; ESP32S3WROOM1UN16R2
JP1: JP2Q
LED1: LEDCHIP-LED0805; CHIP-LED0805
R55: 1k; R0402
R56, R57, R59, R60: 100k; R0402
R58: 0R; R0402
S1, S2: 10-XX; B3F-10XX

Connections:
+3V3: C79.+, C80.+, C81.1, C82.1, IC15.2 (3V3), R56.2, R57.2, R58.2, R59.2; also elsewhere on the board
ESP32_RESET: C77.1, IC15.3 (EN), R60.2, S1.1 (S), S1.2 (S1); also elsewhere on the board
GND: C77.2, C78.2, C79.-, C80.-, C81.2, C82.2, IC15.1 (GND), IC15.40 (GND), IC15.41 (GND), IC15.42 (GND), IC15.43 (GND), IC15.44 (GND), IC15.45 (GND), IC15.46 (GND), IC15.47 (GND), IC15.48 (GND), IC15.49 (GND), JP1.3, LED1.C, R60.1, S1.3, S1.4 (P1), S2.3, S2.4 (P1); also elsewhere on the board
unnamed: JP1.1, R58.1
unnamed: LED1.A, R55.2
unnamed: IC15.38 (IO2), R55.1
PROG: C78.1, IC15.27 (IO0), R59.1, S2.1 (S), S2.2 (S1)
PROG_RX: IC15.36 (RXD0), JP1.2, R56.1
PROG_TX: IC15.37 (TXD0), JP1.4, R57.1
SPI1_MISO: IC15.4 (IO4); also elsewhere on the board
SPI1_MOSI: IC15.5 (IO5); also elsewhere on the board
SPI1_NSS: IC15.7 (IO7); also elsewhere on the board
SPI1_SCK: IC15.6 (IO6); also elsewhere on the board

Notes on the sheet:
MCU MAIN
ESP32 Wifi modul
Projekt: Sběr env. dat
9. 2. 2023
Martin Krásl, 2023

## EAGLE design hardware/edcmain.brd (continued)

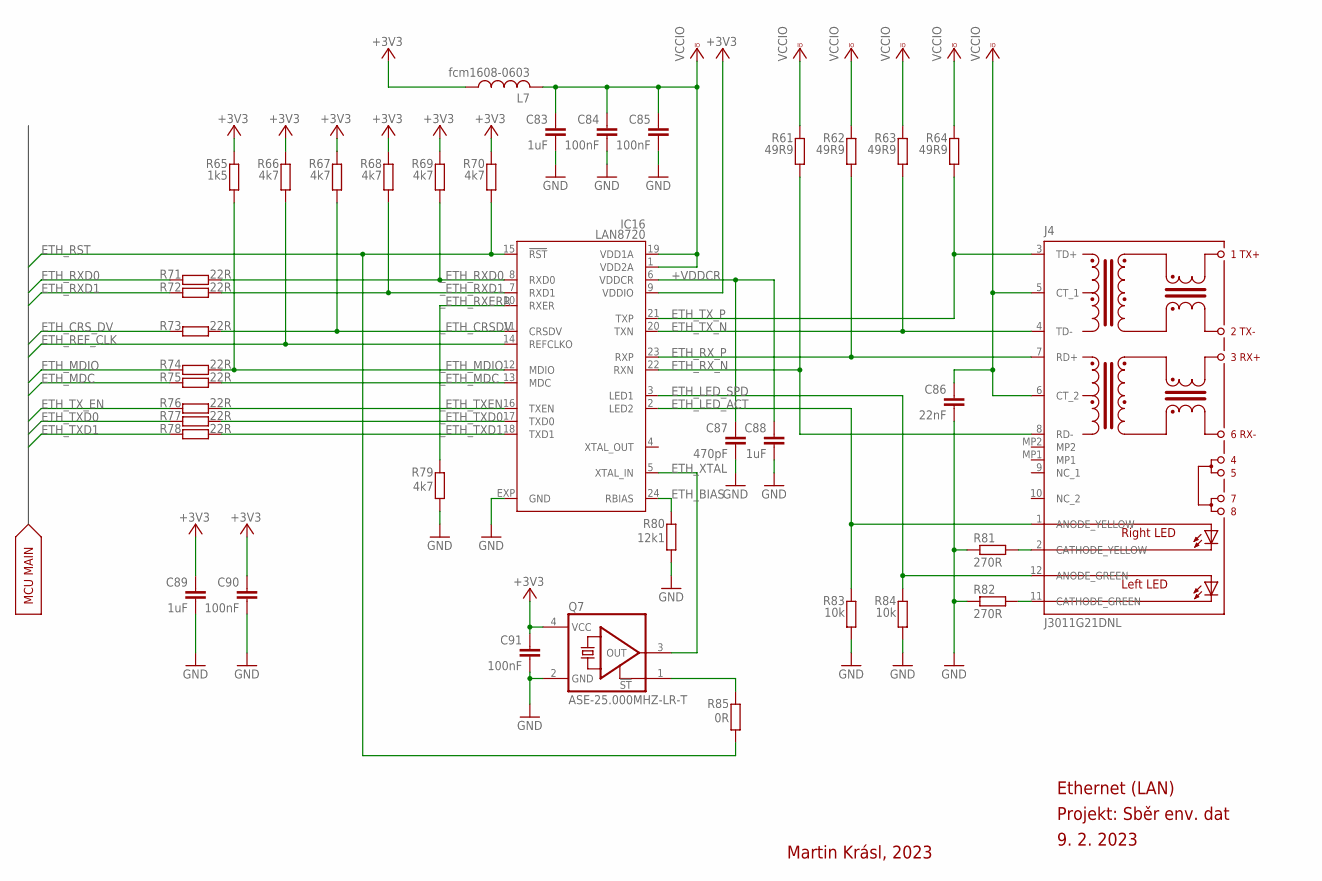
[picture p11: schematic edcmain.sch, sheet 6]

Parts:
C83, C88, C89: 1uF; C0402
C84, C85, C90, C91: 100nF; C0402
C86: 22nF; C0402
C87: 470pF; C0402
IC16: LAN8720; QFN24
J4: J3011G21DNL
L7: fcm1608-0603; L2012C
Q7: ASE-25.000MHZ-LR-T; CRYSTAL3.2X2.5
R61, R62, R63, R64: 49R9; R0402
R65: 1k5; R0402
R66, R67, R68, R69, R70, R79: 4k7; R0402
R71, R72, R73, R74, R75, R76, R77, R78: 22R; R0402
R80: 12k1; R0402
R81, R82: 270R; R0402
R83, R84: 10k; R0402
R85: 0R; R0402

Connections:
+3V3: C89.1, C90.1, C91.1, IC16.9 (VDDIO), L7.1, Q7.4 (VCC), R65.2, R66.2, R67.2, R68.2, R69.2, R70.2; also elsewhere on the board
+VDDCR: C87.1, C88.2, IC16.6 (VDDCR)
ETH_BIAS: IC16.24 (RBIAS), R80.1
ETH_CRS_DV: R73.1; also elsewhere on the board
ETH_LED_ACT: IC16.2 (LED2), J4.1 (ANODE_YELLOW), R83.2
ETH_LED_SPD: IC16.3 (LED1), J4.12 (ANODE_GREEN), R84.2
ETH_MDC: R75.1; also elsewhere on the board
ETH_MDIO: R74.1; also elsewhere on the board
ETH_REF_CLK: IC16.14 (REFCLKO), R66.1; also elsewhere on the board
ETH_RST: IC16.15 (!RST), R70.1, R85.2; also elsewhere on the board
ETH_RXD0: R71.1; also elsewhere on the board
ETH_RXD1: R72.1; also elsewhere on the board
ETH_RX_N: IC16.22 (RXN), J4.8 (RD-), R61.1
ETH_RX_P: IC16.23 (RXP), J4.7 (RD+), R62.1
ETH_TXD0: R77.1; also elsewhere on the board
ETH_TXD1: R78.1; also elsewhere on the board
ETH_TX_EN: R76.1; also elsewhere on the board
ETH_TX_N: IC16.20 (TXN), J4.4 (TD-), R63.1
ETH_TX_P: IC16.21 (TXP), J4.3 (TD+), R64.1
ETH_XTAL: IC16.5 (XTAL_IN), Q7.3 (OUT)
GND: C83.2, C84.2, C85.2, C86.2, C87.2, C88.1, C89.2, C90.2, C91.2, IC16.EXP (GND), Q7.2 (GND), R79.1, R80.2, R81.2, R82.2, R83.1, R84.1; also elsewhere on the board
unnamed: Q7.1 (!ST), R85.1
unnamed: J4.2 (CATHODE_YELLOW), R81.1
unnamed: J4.11 (CATHODE_GREEN), R82.1
VCCIO: C83.1, C84.1, C85.1, C86.1, IC16.1 (VDD2A), IC16.19 (VDD1A), J4.5 (CT_1), J4.6 (CT_2), L7.2, R61.2, R62.2, R63.2, R64.2
_ETH_CRSDV: IC16.11 (CRSDV), R67.1, R73.2
_ETH_MDC: IC16.13 (MDC), R75.2
_ETH_MDIO: IC16.12 (MDIO), R65.1, R74.2
_ETH_RXD0: IC16.8 (RXD0), R69.1, R71.2
_ETH_RXD1: IC16.7 (RXD1), R68.1, R72.2
_ETH_RXERR: IC16.10 (RXER), R79.2
_ETH_TXD0: IC16.17 (TXD0), R77.2
_ETH_TXD1: IC16.18 (TXD1), R78.2
_ETH_TXEN: IC16.16 (TXEN), R76.2

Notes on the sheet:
MCU MAIN
Ethernet (LAN)
Projekt: Sběr env. dat
9. 2. 2023
Martin Krásl, 2023

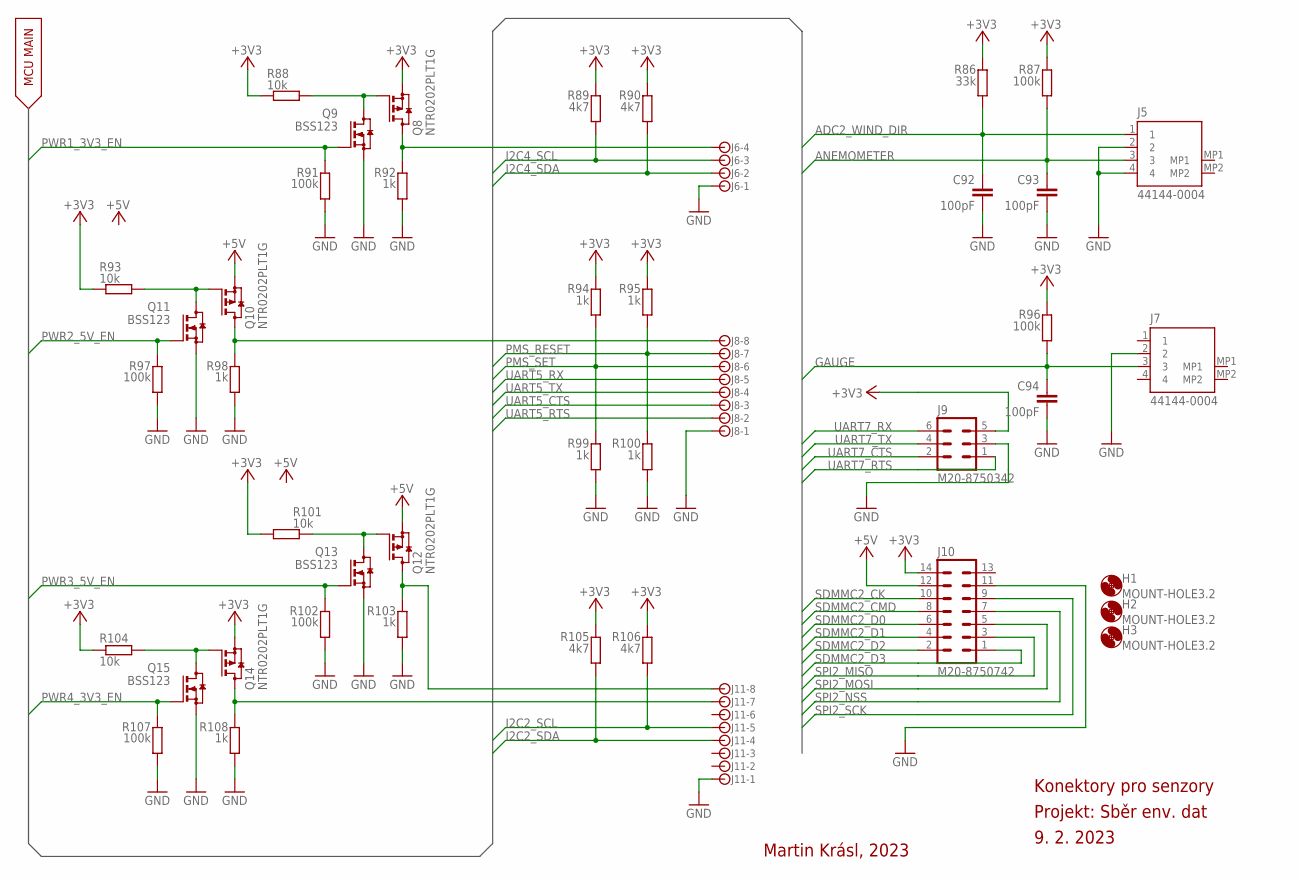
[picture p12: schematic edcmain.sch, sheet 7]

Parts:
C92, C93, C94: 100pF; C0402
H1, H2, H3: MOUNT-HOLE3.2; 3,2
J5, J7: 44144-0004; 441440004
J6: JST-XH-4; B4B-XH-A
J8, J11: JST-XH-8; B8B-XH-A
J9: M20-8750342; M208750342
J10: M20-8750742; M208750742
Q8, Q10, Q12, Q14: NTR0202PLT1G; SOT23
Q9, Q11, Q13, Q15: BSS123; SOT23
R86: 33k; R0402
R87, R91, R96, R97, R102, R107: 100k; R0402
R88, R93, R101, R104: 10k; R0402
R89, R90, R105, R106: 4k7; R0402
R92, R94, R95, R98, R99, R100, R103, R108: 1k; R0402

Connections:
+3V3: J9.5, J10.14, Q8.2 (S), Q14.2 (S), R86.2, R87.2, R88.1, R89.2, R90.2, R93.1, R94.2, R95.2, R96.2, R101.1, R104.1, R105.2, R106.2; also elsewhere on the board
+5V: J10.12, Q10.2 (S), Q12.2 (S); also elsewhere on the board
ADC2_WIND_DIR: C92.1, J5.1, R86.1; also elsewhere on the board
ANEMOMETER: C93.1, J5.3, R87.1; also elsewhere on the board
GAUGE: C94.1, J7.3, R96.1; also elsewhere on the board
GND: C92.2, C93.2, C94.2, J5.2, J5.4, J6.1, J7.2, J8.1, J9.3, J10.11, J11.1, Q9.2 (S), Q11.2 (S), Q13.2 (S), Q15.2 (S), R91.1, R92.1, R97.1, R98.1, R99.1, R100.1, R102.1, R103.1, R107.1, R108.1; also elsewhere on the board
I2C2_SCL: J11.5, R106.1; also elsewhere on the board
I2C2_SDA: J11.4, R105.1; also elsewhere on the board
I2C4_SCL: J6.3, R89.1; also elsewhere on the board
I2C4_SDA: J6.2, R90.1; also elsewhere on the board
unnamed: J11.7, Q14.3 (D), R108.2
unnamed: J11.8, Q12.3 (D), R103.2
unnamed: Q12.1 (G), Q13.3 (D), R101.2
unnamed: Q10.1 (G), Q11.3 (D), R93.2
unnamed: J8.8, Q10.3 (D), R98.2
unnamed: Q8.1 (G), Q9.3 (D), R88.2
unnamed: J6.4, Q8.3 (D), R92.2
unnamed: Q14.1 (G), Q15.3 (D), R104.2
PMS_RESET: J8.7, R95.1, R100.2; also elsewhere on the board
PMS_SET: J8.6, R94.1, R99.2; also elsewhere on the board
PWR1_3V3_EN: Q9.1 (G), R91.2; also elsewhere on the board
PWR2_5V_EN: Q11.1 (G), R97.2; also elsewhere on the board
PWR3_5V_EN: Q13.1 (G), R102.2; also elsewhere on the board
PWR4_3V3_EN: Q15.1 (G), R107.2; also elsewhere on the board
SDMMC2_CK: J10.10; also elsewhere on the board
SDMMC2_CMD: J10.8; also elsewhere on the board
SDMMC2_D0: J10.6; also elsewhere on the board
SDMMC2_D1: J10.4; also elsewhere on the board
SDMMC2_D2: J10.2; also elsewhere on the board
SDMMC2_D3: J10.1; also elsewhere on the board
SPI2_MISO: J10.3; also elsewhere on the board
SPI2_MOSI: J10.5; also elsewhere on the board
SPI2_NSS: J10.7; also elsewhere on the board
SPI2_SCK: J10.9; also elsewhere on the board
UART5_CTS: J8.3; also elsewhere on the board
UART5_RTS: J8.2; also elsewhere on the board
UART5_RX: J8.5; also elsewhere on the board
UART5_TX: J8.4; also elsewhere on the board
UART7_CTS: J9.2; also elsewhere on the board
UART7_RTS: J9.1; also elsewhere on the board
UART7_RX: J9.6; also elsewhere on the board
UART7_TX: J9.4; also elsewhere on the board

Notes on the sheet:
MCU MAIN
Konektory pro senzory
Projekt: Sběr env. dat
9. 2. 2023
Martin Krásl, 2023

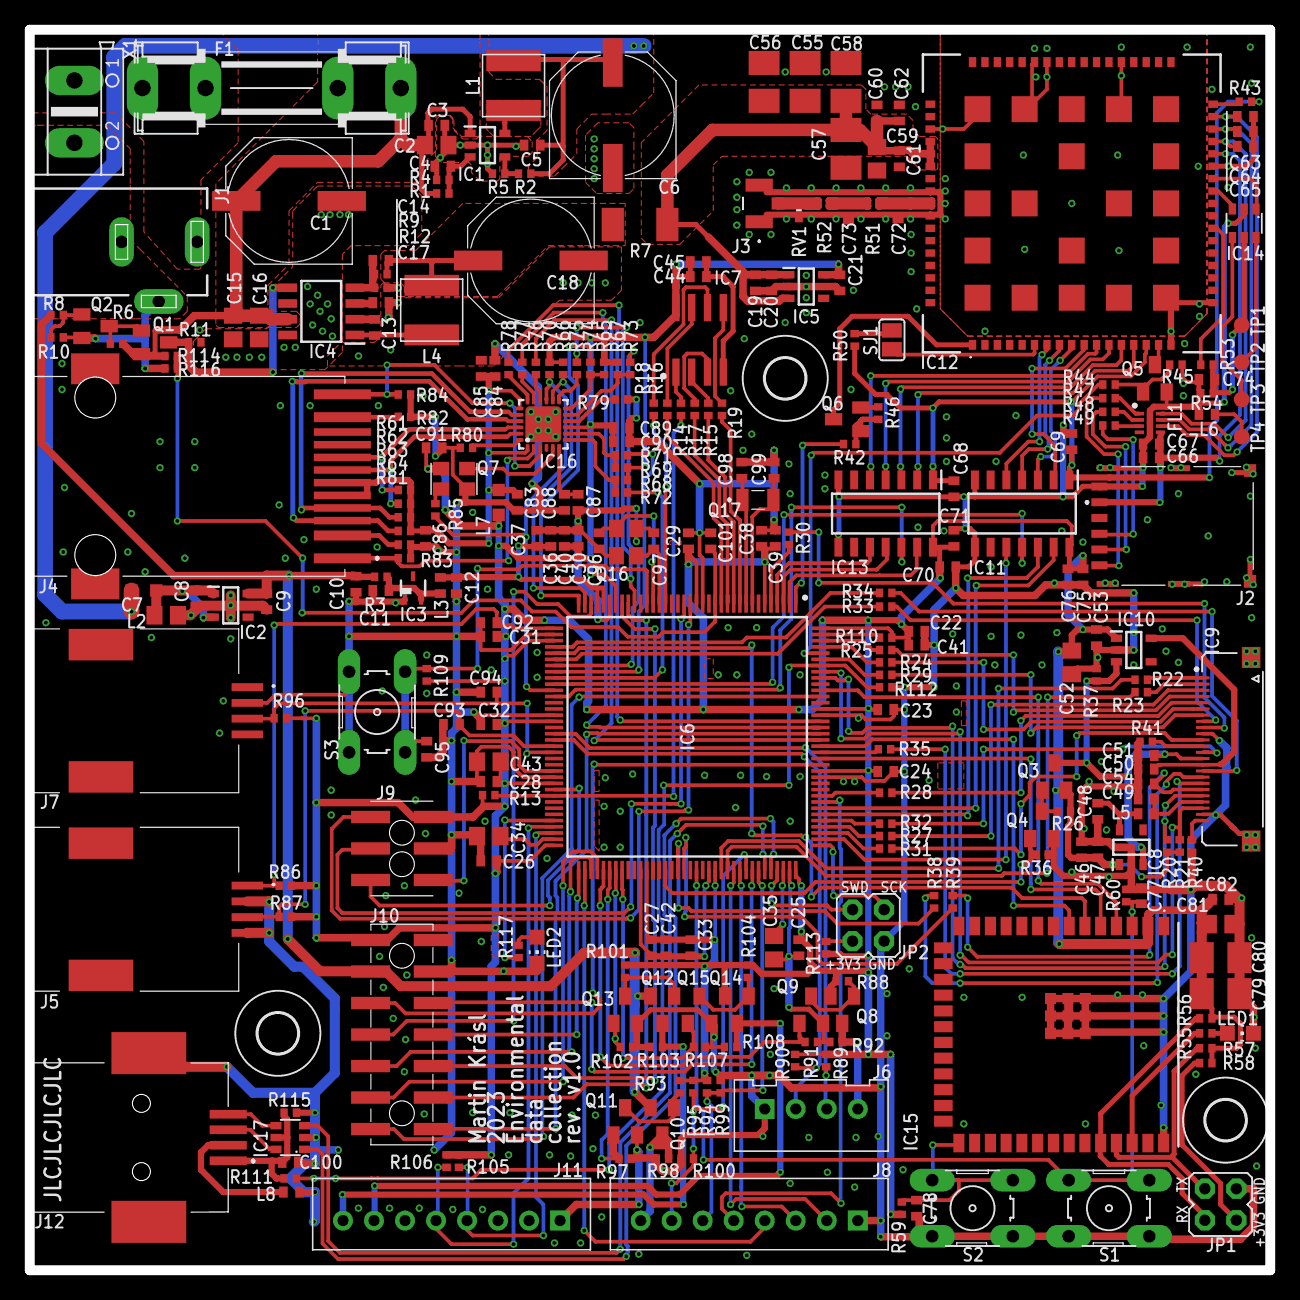
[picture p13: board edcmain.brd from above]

Board: 2 copper layers, 100.0 x 100.0 mm, 292 parts (1 on the bottom side), 222 nets.

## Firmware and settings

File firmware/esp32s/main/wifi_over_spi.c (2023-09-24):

#include "wifi_over_spi.h"

#include <string.h>
#include <assert.h>
#include <sys/param.h>

#include "freertos/FreeRTOS.h"
#include "freertos/task.h"
#include "freertos/event_groups.h"

#include "driver/spi_slave.h"
#include "driver/gpio.h"

#include "esp_system.h"
#include "esp_wifi.h"
#include "esp_event.h"
#include "esp_log.h"
#include "esp_netif.h"

#include "nvs_flash.h"

#include "lwip/err.h"
#include "lwip/sockets.h"
#include "lwip/dns.h"
#include "lwip/sys.h"

static const char *TAG = "wifi_over_spi";

#define _LO(x)    ((x) & 0x00FFU)
#define _HI(x)   (((x) & 0xFF00U) >> 8U)
#define _LOHI(x) ((uint16_t)(x[0]) | ((uint16_t)(x[1]) << (uint16_t)8))

/// ####################################################################################################################
/// SPI registers
/// ####################################################################################################################

// Event group
static EventGroupHandle_t wos_event_group;
static struct wifi_over_spi_registers registers = {0}; // __attribute__((packed, aligned(4)))

/// ####################################################################################################################
/// LED Blink
/// ####################################################################################################################

#define GPIO_LED      2

static void led_task(void *pvParameters)
{
	gpio_reset_pin(GPIO_LED);
	gpio_set_direction(GPIO_LED, GPIO_MODE_OUTPUT);

	static uint8_t state = 0;

	while (1) {
		gpio_set_level(GPIO_LED, state);
		state = !state;
		vTaskDelay(500 / portTICK_PERIOD_MS);
	}
}

/// ####################################################################################################################
/// TCP Client
/// ####################################################################################################################

static void tcp_client_task(void *pvParameters)
{
	int err = 0;

	while (1) {
		if(xEventGroupGetBits(wos_event_group) & ESP32_REGISTER_ADDRESS_STATUS_TCP_FAIL_BIT) {
			ESP_LOGE(TAG, "TCP connection failed!");
		}
		
		if(xEventGroupGetBits(wos_event_group) & ESP32_REGISTER_ADDRESS_STATUS_TCP_CONNECTED_BIT) {
			xEventGroupSetBits(wos_event_group, ESP32_REGISTER_ADDRESS_STATUS_TCP_DISCONNECTED_BIT);
			ESP_LOGI(TAG, "TCP connection ended");
		}

		// Clear state machine
		xEventGroupClearBits(wos_event_group,
				ESP32_REGISTER_ADDRESS_CONTROL_TCP_SEND_REQUEST_BIT |
				ESP32_REGISTER_ADDRESS_CONTROL_TCP_DISCONNECT_REQUEST_BIT |
				ESP32_REGISTER_ADDRESS_STATUS_TCP_CONNECTED_BIT |
				ESP32_REGISTER_ADDRESS_STATUS_TCP_SENT_BIT);

		// Wait for request
		xEventGroupWaitBits(wos_event_group,
				ESP32_REGISTER_ADDRESS_CONTROL_TCP_CONNECT_REQUEST_BIT |
				ESP32_REGISTER_ADDRESS_STATUS_WIFI_CONNECTED_BIT, pdFALSE, pdTRUE, portMAX_DELAY);

		// Clear request and result bits
		xEventGroupClearBits(wos_event_group,
				ESP32_REGISTER_ADDRESS_CONTROL_TCP_CONNECT_REQUEST_BIT |
				ESP32_REGISTER_ADDRESS_STATUS_TCP_DISCONNECTED_BIT |
				ESP32_REGISTER_ADDRESS_STATUS_TCP_FAIL_BIT);
	
		// Get IP first by domain name
		ip_addr_t resolved_ip;
		for(int retry = 0; retry < 10; ++retry) {
			// Make sure it is terminated!
			registers.tcp_domain[sizeof(registers.tcp_domain) - 1] = '\0';
			// Info
			ESP_LOGI(TAG, "dns_gethostbyname '%s'", (const char*)registers.tcp_domain);
			// Try to resolve IP
			err = dns_gethostbyname((const char*)registers.tcp_domain, &resolved_ip, NULL, NULL);
			if(err == ERR_OK) {
				break;
			}
			ESP_LOGW(TAG, "dns_gethostbyname error: errno %d", err);
			vTaskDelay(5000 / portTICK_PERIOD_MS);
		}
		
		// Error obtaining IP via DNS
		if(err != ERR_OK) {
			xEventGroupSetBits(wos_event_group, ESP32_REGISTER_ADDRESS_STATUS_TCP_FAIL_BIT);
			continue;
		}
		
		ESP_LOGI(TAG, "dns_gethostbyname OK!");

		// Convert ip_addr_t --> u32 in_addr_t
		struct in_addr ip_addr;
		ip_addr.s_addr = ip4_addr_get_u32(&resolved_ip.u_addr.ip4);
		
		// Configure TCP connection
		struct sockaddr_in dest_addr;
		memset(&dest_addr, 0, sizeof(dest_addr));
		dest_addr.sin_family = AF_INET;
		dest_addr.sin_addr = ip_addr;
		dest_addr.sin_port = htons(_LOHI(registers.tcp_port));
	
		// Create socket
		int sock;
		for(int retry = 0; retry < 10; ++retry) {
			sock = lwip_socket(AF_INET, SOCK_STREAM, IPPROTO_IP);
			if(sock >= 0) {
				break;
			}
			ESP_LOGW(TAG, "Unable to create socket: errno %d", errno);
			vTaskDelay(1000 / portTICK_PERIOD_MS);
		}
		
		// Error creating socket
		if(sock < 0) {
			xEventGroupSetBits(wos_event_group, ESP32_REGISTER_ADDRESS_STATUS_TCP_FAIL_BIT);
			continue;
		}
		
		// Print debug message
		char ip_str[32];
		inet_ntoa_r(ip_addr, ip_str, sizeof(ip_str));	
		ESP_LOGI(TAG, "Socket %d created, connecting to %s:%d", sock, ip_str, ntohs(dest_addr.sin_port));

		// Connect socket to server
		for(int retry = 0; retry < 10; ++retry) {
			err = lwip_connect(sock, (struct sockaddr *)&dest_addr, sizeof(struct sockaddr_in6));
			if(err == 0) {
				break;
			}
			ESP_LOGW(TAG, "Socket unable to connect: errno %d", errno);
			vTaskDelay(1000 / portTICK_PERIOD_MS);
		}
		
		// Error cannot connect
		if(err != 0) {
			// Free socket
			lwip_shutdown(sock, 0);
			lwip_close(sock);
			xEventGroupSetBits(wos_event_group, ESP32_REGISTER_ADDRESS_STATUS_TCP_FAIL_BIT);
			continue;
		}
		
		// Success
		xEventGroupSetBits(wos_event_group, ESP32_REGISTER_ADDRESS_STATUS_TCP_CONNECTED_BIT);
		ESP_LOGI(TAG, "Successfully connected");

		
		TimeOut_t xTimeOut;
		TickType_t xTicksToWait = 10000 / portTICK_PERIOD_MS;
		// Reset timeout
		vTaskSetTimeOutState(&xTimeOut);
		// Do for every transmit
		while(!(xEventGroupGetBits(wos_event_group) & ESP32_REGISTER_ADDRESS_CONTROL_TCP_DISCONNECT_REQUEST_BIT)) {
			if(xTaskCheckForTimeOut(&xTimeOut, &xTicksToWait) != pdFALSE) {
				// Timeout
				ESP_LOGE(TAG, "Send request timeout!");
				xEventGroupSetBits(wos_event_group, ESP32_REGISTER_ADDRESS_STATUS_TCP_FAIL_BIT);
				break;
			}
			// Do for every request
			if(xEventGroupWaitBits(wos_event_group, ESP32_REGISTER_ADDRESS_CONTROL_TCP_SEND_REQUEST_BIT | ESP32_REGISTER_ADDRESS_CONTROL_TCP_DISCONNECT_REQUEST_BIT, pdFALSE, pdFALSE, xTicksToWait) & ESP32_REGISTER_ADDRESS_CONTROL_TCP_SEND_REQUEST_BIT) {
				xEventGroupClearBits(wos_event_group, ESP32_REGISTER_ADDRESS_STATUS_TCP_SENT_BIT);
				uint16_t cnt = _LOHI(registers.tcp_buffer_tx_len);
				ESP_LOGI(TAG, "Let's send 0x%04X == %d bytes ...", cnt, (int)cnt);
				err = lwip_send(sock, registers.tcp_buffer_tx, cnt, 0);
				if(err < 0) {
					continue;
				}
				xEventGroupSetBits(wos_event_group, ESP32_REGISTER_ADDRESS_STATUS_TCP_SENT_BIT);
				xEventGroupClearBits(wos_event_group, ESP32_REGISTER_ADDRESS_CONTROL_TCP_SEND_REQUEST_BIT);
				// Reset timeout
				vTaskSetTimeOutState(&xTimeOut);
				ESP_LOGI(TAG, "Data successfully sent!");
			}
		}

		// Free socket
		ESP_LOGI(TAG, "Shutting down socket and restarting...");
		lwip_shutdown(sock, 0);
		lwip_close(sock);
	}
	
	vTaskDelete(NULL);
}

/// ####################################################################################################################
/// WiFi station
/// ####################################################################################################################

static void wifi_event_handler(void* arg, esp_event_base_t event_base, int32_t event_id, void* event_data)
{
	static int s_retry_num = 0;
	
	if(event_base == WIFI_EVENT) {
		if(event_id == WIFI_EVENT_STA_START) {
			esp_wifi_connect();
			return;
		}
		
		if(event_id == WIFI_EVENT_STA_DISCONNECTED) {
			if(s_retry_num++ < 10) {
				esp_wifi_connect();
				ESP_LOGI(TAG, "retry to connect to the AP");
				return;
			}
			xEventGroupSetBits(wos_event_group, ESP32_REGISTER_ADDRESS_STATUS_WIFI_FAIL_BIT);
			ESP_LOGI(TAG,"connect to the AP fail");
			return;
		}
	}
	
	if(event_base == IP_EVENT) {
		if(event_id == IP_EVENT_STA_GOT_IP) {
			ip_event_got_ip_t* event = (ip_event_got_ip_t*) event_data;
			ESP_LOGI(TAG, "got ip:" IPSTR, IP2STR(&event->ip_info.ip));
			s_retry_num = 0;
			xEventGroupSetBits(wos_event_group, ESP32_REGISTER_ADDRESS_STATUS_WIFI_CONNECTED_BIT);
			return;
		}
	}
}

static void wifi_sta_task(void *pvParameters)
{		
	esp_netif_create_default_wifi_sta();

	wifi_init_config_t cfg = WIFI_INIT_CONFIG_DEFAULT();
	ESP_ERROR_CHECK(esp_wifi_init(&cfg));

	esp_event_handler_instance_t instance_any_id;
	esp_event_handler_instance_t instance_got_ip;
	ESP_ERROR_CHECK(esp_event_handler_instance_register(WIFI_EVENT, ESP_EVENT_ANY_ID, &wifi_event_handler, NULL, &instance_any_id));
	ESP_ERROR_CHECK(esp_event_handler_instance_register(IP_EVENT, IP_EVENT_STA_GOT_IP, &wifi_event_handler, NULL, &instance_got_ip));

	while(1) {
		// Wait for connection request
		xEventGroupWaitBits(wos_event_group, ESP32_REGISTER_ADDRESS_CONTROL_WIFI_CONNECT_REQUEST_BIT, pdFALSE, pdFALSE, portMAX_DELAY);
		
		xEventGroupClearBits(wos_event_group,
				ESP32_REGISTER_ADDRESS_CONTROL_WIFI_CONNECT_REQUEST_BIT |
				ESP32_REGISTER_ADDRESS_STATUS_WIFI_FAIL_BIT |
				ESP32_REGISTER_ADDRESS_STATUS_WIFI_CONNECTED_BIT);
	
		// SSID and PASSWORD should be ready
		wifi_config_t wifi_config = {
			.sta = {
				.threshold.authmode = WIFI_AUTH_WPA_WPA2_PSK,
				.sae_pwe_h2e = WPA3_SAE_PWE_BOTH,
			},
		};	
		
		// Copy SSID
		assert(sizeof(wifi_config.sta.ssid) == sizeof(registers.wifi_ssid));
		memcpy(&wifi_config.sta.ssid, registers.wifi_ssid, sizeof(registers.wifi_ssid));
		wifi_config.sta.ssid[sizeof(wifi_config.sta.ssid) - 1] = '\0';
		
		// Copy PASSWORD
		assert(sizeof(wifi_config.sta.password) == sizeof(registers.wifi_password));
		memcpy(&wifi_config.sta.password, registers.wifi_password, sizeof(registers.wifi_password));
		wifi_config.sta.password[sizeof(wifi_config.sta.password) - 1] = '\0';

		// Debug
		ESP_LOGI(TAG, "SSID: '%s', PASSWORD '%s'", wifi_config.sta.ssid, wifi_config.sta.password);
				
		// WiFi start internal state machine
		ESP_ERROR_CHECK(esp_wifi_set_mode(WIFI_MODE_STA));
		ESP_ERROR_CHECK(esp_wifi_set_config(WIFI_IF_STA, &wifi_config));
		ESP_ERROR_CHECK(esp_wifi_start());

		// Wait for error or another request
		xEventGroupWaitBits(wos_event_group, ESP32_REGISTER_ADDRESS_STATUS_WIFI_FAIL_BIT, pdFALSE, pdFALSE, portMAX_DELAY);
		
		// Error!		
		ESP_LOGE(TAG, "WiFi connection failed! Reset...");
		
		// WiFi stop internal state machine
		esp_wifi_stop();
	}

	// The event will not be processed after unregister
	ESP_ERROR_CHECK(esp_event_handler_instance_unregister(IP_EVENT, IP_EVENT_STA_GOT_IP, instance_got_ip));
	ESP_ERROR_CHECK(esp_event_handler_instance_unregister(WIFI_EVENT, ESP_EVENT_ANY_ID, instance_any_id));
	
	vTaskDelete(NULL);
}

/// ####################################################################################################################
/// SPI Slave
/// ####################################################################################################################
#define GPIO_MOSI         5
#define GPIO_MISO         4
#define GPIO_SCLK         6
#define GPIO_CS           7
#define RCV_HOST          SPI3_HOST
#define SPI_SLAVE_VERBOSE 0

// Main application
void spi_slave_task(void *pvParameters)
{
	esp_err_t ret;

	// Configuration for the SPI bus
	spi_bus_config_t buscfg = {
		.mosi_io_num = GPIO_MOSI,
		.miso_io_num = GPIO_MISO,
		.sclk_io_num = GPIO_SCLK,
		.quadwp_io_num = -1,
		.quadhd_io_num = -1,
	};

	// Configuration for the SPI slave interface
	spi_slave_interface_config_t slvcfg = {
		.mode = 0,
		.spics_io_num = GPIO_CS,
		.queue_size = 3,
		.flags = 0,
	};

	// Enable pull-ups on SPI lines so we don't detect rogue pulses when no master is connected.
	gpio_set_pull_mode(GPIO_MOSI, GPIO_PULLUP_ONLY);
	gpio_set_pull_mode(GPIO_SCLK, GPIO_PULLUP_ONLY);
	gpio_set_pull_mode(GPIO_CS, GPIO_PULLUP_ONLY);


	// Initialise SPI slave interface
	ret = spi_slave_initialize(RCV_HOST, &buscfg, &slvcfg, SPI_DMA_CH_AUTO);
	assert(ret == ESP_OK);

	static WORD_ALIGNED_ATTR char sendbuf[ESP32_SPI_MESSAGE_MAX_SIZE] = "";
	static WORD_ALIGNED_ATTR char recvbuf[ESP32_SPI_MESSAGE_MAX_SIZE] = "";
	memset(recvbuf, 0, 33);
	spi_slave_transaction_t t;
	memset(&t, 0, sizeof(t));

	while(1) {
		// Clear receive buffer, set send buffer to something sane
		memset(sendbuf, 0xA5, sizeof(sendbuf));
		memset(recvbuf, 0xA5, sizeof(recvbuf));

		memcpy(sendbuf, "123456789", 9);

		// Set up a transaction of 128 bytes to send/receive
		t.length = ESP32_SPI_MESSAGE_MAX_SIZE * 8;
		t.tx_buffer = sendbuf;
		t.rx_buffer = recvbuf;
		
		ret = spi_slave_transmit(RCV_HOST, &t, portMAX_DELAY);
		if (ret == ESP_OK) {	
			size_t received_bytes = (int)t.trans_len / 8;
			
			if(recvbuf[0] == 0x01) {
				// COMMAND_WRITE
				if(received_bytes > 3) {
					uint16_t address = (recvbuf[2] << 8U) | recvbuf[1];
					uint16_t count = received_bytes - 3;
					if(address != ESP32_REGISTER_ADDRESS_CONTROLSTATUS) {
						// Perform copy
						#define min(a,b) ((a) < (b) ? (a) : (b))
						uint16_t max_copy_bytes = sizeof(registers) - (address % sizeof(registers));
						memcpy((void*)((uint8_t*)&registers + address), &recvbuf[3], min(max_copy_bytes, count));

						// Debug
						#if SPI_SLAVE_VERBOSE
							printf("Write @ 0x%04X: ", address);
							for(uint32_t i = 3; i < received_bytes; ++i) {
								printf("%02X ", recvbuf[i]);
							}
							printf("\n");
						#endif // SPI_SLAVE_VERBOSE
					} else {
						xEventGroupSetBits(wos_event_group, recvbuf[3]);
						#if SPI_SLAVE_VERBOSE
							printf("Write @ 0x%04X (SET-CONTROL): %02X\n", address, recvbuf[3]);
						#endif // SPI_SLAVE_VERBOSE
					}
				}
			} else if(recvbuf[0] == 0x02) {
				// COMMAND_READ
				uint16_t address = (recvbuf[2] << 8U) | recvbuf[1];
				uint16_t count   = (recvbuf[4] << 8U) | recvbuf[3];

				// Clear receive buffer, set send buffer to something sane
				memset(sendbuf, 0xA5, sizeof(sendbuf));
				memset(recvbuf, 0xA5, sizeof(recvbuf));

				if(address != ESP32_REGISTER_ADDRESS_CONTROLSTATUS) {
					// Load memory to DMA buffer
					uint16_t max_copy_bytes = sizeof(registers) - (address % sizeof(registers));
					memcpy(sendbuf, (void*)((uint8_t*)&registers + address), min(max_copy_bytes, min(sizeof(sendbuf), count)));

					#if SPI_SLAVE_VERBOSE
						printf("Read  @ 0x%04X count %d: ", address, count);
						for(uint32_t i = 0; i < count; ++i) {
							printf("%02X ", sendbuf[i]);
						}
						printf("\n");
					#endif // SPI_SLAVE_VERBOSE
				} else {
					sendbuf[0] = _HI(xEventGroupGetBits(wos_event_group));
					#if SPI_SLAVE_VERBOSE
						printf("Read @ 0x%04X (GET-STATUS): %02X\n", address, sendbuf[0]);
					#endif // SPI_SLAVE_VERBOSE
				}

				// Set up a transaction
				t.length = ESP32_SPI_MESSAGE_MAX_SIZE * 8;
				t.tx_buffer = sendbuf;
				t.rx_buffer = recvbuf;
				spi_slave_transmit(RCV_HOST, &t, portMAX_DELAY);
			} else {
				#if SPI_SLAVE_VERBOSE
					printf("SPI Error\n");
				#endif // SPI_SLAVE_VERBOSE
			}
		}
	}
}

/// ####################################################################################################################
/// Main
/// ####################################################################################################################

void app_main(void)
{	
	// Initialise NVS
	esp_err_t ret = nvs_flash_init();
	if(ret == ESP_ERR_NVS_NO_FREE_PAGES || ret == ESP_ERR_NVS_NEW_VERSION_FOUND) {
		ESP_ERROR_CHECK(nvs_flash_erase());
		ret = nvs_flash_init();
	}
	ESP_ERROR_CHECK(ret);
	
	ESP_ERROR_CHECK(esp_netif_init());
	ESP_ERROR_CHECK(esp_event_loop_create_default());
	
	wos_event_group = xEventGroupCreate();

	ESP_LOGI(TAG, "ESP_WIFI_MODE_STA");
	
	gpio_set_direction(GPIO_MOSI, GPIO_MODE_INPUT);
	gpio_set_direction(GPIO_MISO, GPIO_MODE_INPUT);
	gpio_set_direction(GPIO_SCLK, GPIO_MODE_INPUT);
	gpio_set_direction(GPIO_CS, GPIO_MODE_INPUT);

	xTaskCreate(spi_slave_task, "spi_slave_task", 4096, NULL, 5, NULL);	
	xTaskCreate(led_task, "led_task", 4096, NULL, 5, NULL);
	xTaskCreate(wifi_sta_task, "wifi_sta_task", 4096, NULL, 5, NULL);
	xTaskCreate(tcp_client_task, "tcp_client", 4096, NULL, 5, NULL);
}

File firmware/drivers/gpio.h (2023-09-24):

#ifndef GPIO_H
#define GPIO_H

#include "stm32h7xx.h"

/// Configuration

// LED
#define GPIO_PIN_USER_LED         (struct gpio_pin){.gpio = GPIOE, .pin = 15}

// Camera
#define GPIO_PIN_DCMI_D0          (struct gpio_pin){.gpio = GPIOC, .pin =  6}
#define GPIO_PIN_DCMI_D1          (struct gpio_pin){.gpio = GPIOC, .pin =  7}
#define GPIO_PIN_DCMI_D2          (struct gpio_pin){.gpio = GPIOE, .pin =  0}
#define GPIO_PIN_DCMI_D3          (struct gpio_pin){.gpio = GPIOE, .pin =  1}
#define GPIO_PIN_DCMI_D4          (struct gpio_pin){.gpio = GPIOC, .pin = 11}
#define GPIO_PIN_DCMI_D5          (struct gpio_pin){.gpio = GPIOD, .pin =  3}
#define GPIO_PIN_DCMI_D6          (struct gpio_pin){.gpio = GPIOB, .pin =  8}
#define GPIO_PIN_DCMI_D7          (struct gpio_pin){.gpio = GPIOE, .pin =  6}
#define GPIO_PIN_DCMI_D8          (struct gpio_pin){.gpio = GPIOC, .pin = 10}
#define GPIO_PIN_DCMI_D9          (struct gpio_pin){.gpio = GPIOC, .pin = 12}
#define GPIO_PIN_DCMI_PIXCL       (struct gpio_pin){.gpio = GPIOA, .pin =  6}
#define GPIO_PIN_DCMI_HSYNC       (struct gpio_pin){.gpio = GPIOA, .pin =  4}
#define GPIO_PIN_DCMI_VSYNC       (struct gpio_pin){.gpio = GPIOG, .pin =  9}
#define GPIO_PIN_I2C1_SDA         (struct gpio_pin){.gpio = GPIOB, .pin =  7}
#define GPIO_PIN_I2C1_SCL         (struct gpio_pin){.gpio = GPIOB, .pin =  6}
#define GPIO_PIN_CAM_PWDN         (struct gpio_pin){.gpio = GPIOG, .pin =  4}
#define GPIO_PIN_CAM_RESET        (struct gpio_pin){.gpio = GPIOG, .pin =  5}
#define GPIO_PIN_CAM_XCLK         (struct gpio_pin){.gpio = GPIOB, .pin =  5}
#define GPIO_PIN_CAM_PWR_EN       (struct gpio_pin){.gpio = GPIOG, .pin =  2}

// Sensors
#define GPIO_PIN_I2C4_SDA         (struct gpio_pin){.gpio = GPIOF, .pin = 15}
#define GPIO_PIN_I2C4_SCL         (struct gpio_pin){.gpio = GPIOF, .pin = 14}
#define GPIO_PIN_I2C2_SDA         (struct gpio_pin){.gpio = GPIOB, .pin = 11}
#define GPIO_PIN_I2C2_SCL         (struct gpio_pin){.gpio = GPIOB, .pin = 10}

// Mechanical sensors
#define GPIO_PIN_ANEMOMETER       (struct gpio_pin){.gpio = GPIOG, .pin =  0}
#define GPIO_PIN_GAUGE            (struct gpio_pin){.gpio = GPIOG, .pin =  1}
#define GPIO_PIN_ADC2_WIND_DIR    (struct gpio_pin){.gpio = GPIOA, .pin =  3}

// PMS sensor
#define GPIO_PIN_CON_PMS_RESET    (struct gpio_pin){.gpio = GPIOA, .pin =  8}
#define GPIO_PIN_CON_PMS_SET      (struct gpio_pin){.gpio = GPIOA, .pin = 10}
#define GPIO_PIN_CON_UART5_RTS    (struct gpio_pin){.gpio = GPIOC, .pin =  8}
#define GPIO_PIN_CON_UART5_CTS    (struct gpio_pin){.gpio = GPIOC, .pin =  9}
#define GPIO_PIN_CON_UART5_RX     (struct gpio_pin){.gpio = GPIOD, .pin =  2}
#define GPIO_PIN_CON_UART5_TX     (struct gpio_pin){.gpio = GPIOB, .pin = 13}

// Analog feedback
#define GPIO_PIN_ADC3_BAT_VOLTAGE (struct gpio_pin){.gpio = GPIOF, .pin =  4}

// GSM/LTE
#define GPIO_PIN_UART4_RTS        (struct gpio_pin){.gpio = GPIOA, .pin = 15}
#define GPIO_PIN_UART4_CTS        (struct gpio_pin){.gpio = GPIOB, .pin =  0}
#define GPIO_PIN_UART4_RX         (struct gpio_pin){.gpio = GPIOD, .pin =  0}
#define GPIO_PIN_UART4_TX         (struct gpio_pin){.gpio = GPIOD, .pin =  1}
#define GPIO_PIN_LTE_PWRKEY       (struct gpio_pin){.gpio = GPIOE, .pin =  2}
#define GPIO_PIN_LTE_RESET        (struct gpio_pin){.gpio = GPIOB, .pin =  9}

// External serial device
#define GPIO_PIN_CON_UART7_RTS    (struct gpio_pin){.gpio = GPIOE, .pin =  9}
#define GPIO_PIN_CON_UART7_CTS    (struct gpio_pin){.gpio = GPIOE, .pin = 10}
#define GPIO_PIN_CON_UART7_RX     (struct gpio_pin){.gpio = GPIOF, .pin =  6}
#define GPIO_PIN_CON_UART7_TX     (struct gpio_pin){.gpio = GPIOF, .pin =  7}

// WiFi SPI
#define GPIO_PIN_ESP32_MISO       (struct gpio_pin){.gpio = GPIOB, .pin =  4}
#define GPIO_PIN_ESP32_MOSI       (struct gpio_pin){.gpio = GPIOD, .pin =  7}
#define GPIO_PIN_ESP32_SCK        (struct gpio_pin){.gpio = GPIOA, .pin =  5}
#define GPIO_PIN_ESP32_CS         (struct gpio_pin){.gpio = GPIOG, .pin = 10}

// Ethernet RMII
#define GPIO_PIN_RMII_REFCLK      (struct gpio_pin){.gpio = GPIOA, .pin =  1}
#define GPIO_PIN_RMII_MDIO        (struct gpio_pin){.gpio = GPIOA, .pin =  2}
#define GPIO_PIN_RMII_MDC         (struct gpio_pin){.gpio = GPIOC, .pin =  1}
#define GPIO_PIN_RMII_RXDATAVALID (struct gpio_pin){.gpio = GPIOA, .pin =  7}
#define GPIO_PIN_RMII_RXD0        (struct gpio_pin){.gpio = GPIOC, .pin =  4}
#define GPIO_PIN_RMII_RXD1        (struct gpio_pin){.gpio = GPIOC, .pin =  5}
#define GPIO_PIN_RMII_TXEN        (struct gpio_pin){.gpio = GPIOG, .pin = 11}
#define GPIO_PIN_RMII_TXD0        (struct gpio_pin){.gpio = GPIOG, .pin = 13}
#define GPIO_PIN_RMII_TXD1        (struct gpio_pin){.gpio = GPIOG, .pin = 14}
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
